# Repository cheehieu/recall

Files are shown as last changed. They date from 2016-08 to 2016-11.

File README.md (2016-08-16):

# Overview
Originally called "Reminder", this project is the brainchild of Joel Busa. It was intended to help people who have difficulty remembering whether or not they had completed a short, menial task. Users would simply press a button on the Recall device, and an LED would begin to blink for a duration of 30 minutes. If the user pressed the button again before the 30 minutes had elapsed, the LED would turn off.

[state diagram]

The goals of this design were:
* Small
* Low Power
* Stupid Cheap

[concept drawing]

# Hardware
* BOM
* schematics
* layouts
* gerbers, OSH Park links
* cost of build

## Discrete
* Discrete LED flasher circuit with passive components
** LM3909 equivalent
* Coin cell battery, CR2032 is most cost effective for the capacity, CR2450 (600 mAh), CR2477 (1000 mAh)
* Diffuse push button mechanical switch
* Current shunt for power measurement

## Microcontroller
* PIC10(L)F320 for power/cost/size
** ATTINY5 was lowest cost on DigiKey at $0.30 @ 5k, but 200/25 uA active/standby current at 1.8V
** PIC10LF320/322 is more expensive at $0.38 @ 3k, but 25/0.02 uA active/standby current at 1.8V
* Digital LED flasher circuit, isolation diodes
* Requires an ICSP programmer like PICkit 3 on eBay for $15

## Bluetooth Module
* Rigado BMD-300 for availability/libraries/size/power
* Rigado BMD-350 for size
* Hall effect switch for Baby Guardian
* GPIO breakout for tactile push button switch
* SWD interface for programming

## Custom BLE 
* BLE solution in smallest footprint, low cost
* bypass capacitors, DCDC, LF/HF crystals, PCB PIFA antenna, ceramic chip antenna
* shielding, FCC certification, 
* Hall effect switch for Baby Guardian
* GPIO breakout for tactile push button switch
* SWD interface for programming
* Reference Tindie nRF52 dev board

# Firmware
## PIC
## Nordic
Configured as a beacon, update major on button state change (indicates status in advertising packet to listening phone)
* battery level
* RSSI for distance

# Software
## Android
## iOS
## React Native

# Mechanical
* Silicone button with conductive pad
* Translucent key caps

* 3D design files for enclosure
* 3D design files for Baby Guardian clip
* 3D printed results

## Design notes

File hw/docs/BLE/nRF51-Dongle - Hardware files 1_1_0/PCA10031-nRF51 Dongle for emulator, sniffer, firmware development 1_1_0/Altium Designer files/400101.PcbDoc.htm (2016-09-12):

Reporting Options

# File in Previous Format

Date | : | 9/11/2016
Time | : | 3:55:51 PM
Filename | : | C:\Users\Hieu\Documents\GitHub\recall\hw\docs\BLE\nRF51-Dongle - Hardware files 1_1_0\PCA10031-nRF51 Dongle for emulator, sniffer, firmware development 1_1_0\Altium Designer files\400101.PcbDoc

Version | Warning

This file was generated by an earlier version of the software

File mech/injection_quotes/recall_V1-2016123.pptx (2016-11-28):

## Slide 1

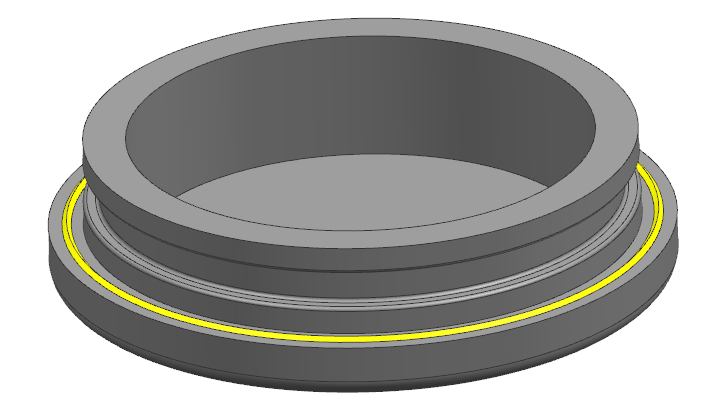
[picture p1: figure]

2. recall_oring_bottom

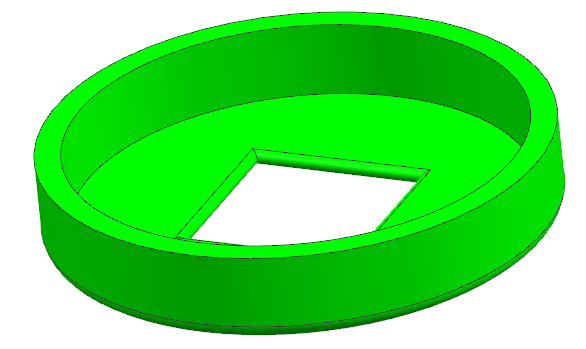
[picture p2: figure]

Suggest using ultrasonic bonding

1.recall_top

Notes:
a. In order to simplify tooling, suggest doing groove on bottom part.
b. Suggest using POM material for these two parts, for its high mechanical strength , and better effect to press the o-ring.

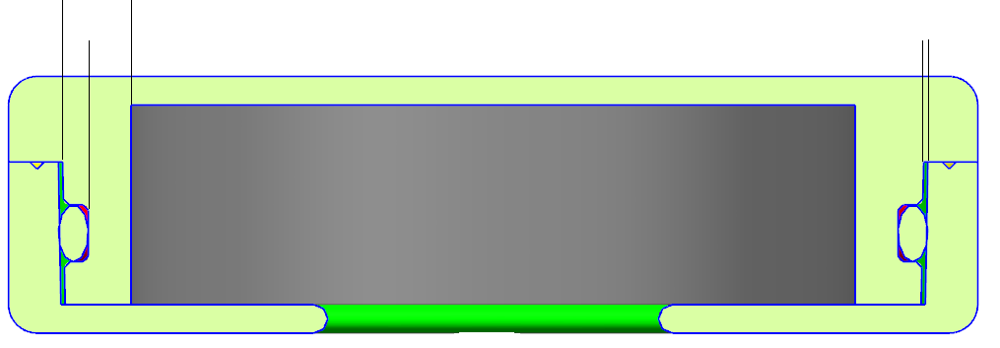
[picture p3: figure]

2.4mm

1.5mm

2. recall_oring_bottom

The gap is 0.15mm

3. o-ring( standard part)

1.recall_top

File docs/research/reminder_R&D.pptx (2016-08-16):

## Reminder R&D

Hieu Nguyen
Intuitive Machines
July 1, 2016

## Reminder

- Overview
  - All hardware
  - Waterproof
  - Stupid cheap
- Usage
  - Press button and an LED blinks lighting up button
  - Blinks for 30 minutes or until pressed again
  - Stick around the house, shower, etc.
- Misc.
  - Battery life should last two years
  - Blink frequency as slow as 1 Hz
  - Target price <$2 at high quantities

Reset

PB

OFF

LED Blink

PB | 30 minutes

## Components

- Transparent silicon rubber button
- 555 timer
- Low power LED
- Watch battery
- Sticky tape for mounting

## Power Analysis

- Requirements:
  - 2 year battery life
  - 30 minute continuous runtime
  - Small “watch battery” button cell
- CR2032 3V 225mAh coin cell ($0.17)
  - 2 years = 17520 hours
  - Max Avg Current = 0.7 * 225 mAh / 17520 hours = ~9 uA

## Solutions

1. Push button control
2. 30 minute timeout
3. Blink LED
- MCU (ATtiny13a)
- 555 CMOS timer
- General purpose 16-stage timer (daisy chained)
- Flip flop
- Multivibrator transistor circuit
- LM3909 LED flasher
- NAND gate multivibrator circuit

## 555 Timer

- Low cost vs. power efficiency
- 30 minute one-shot timer
  - T = 1.1 * R [ohms] * C [Farads] seconds
  - 2 resistors, 2 caps
- LED flasher
  - T = 1 / (0.7*(RA+2RB)*C)
  - F = 1 / (0.693(2R)C Hz [50% duty cycle]
  - 2 resistors, 2 capacitors

## Discrete Multivibrator

- Bistable for storing button input
- Monostable for one shot timer
- Astable for blinking LED
- High freq pulse, divided down with Ripple Counter
- NAND gate waveform generator

## LEDs

- Our eyes perceive different colors at different brightnesses, even though a light might indicate they are the same. Blue and green LEDs always look brighter than red and yellows for the same given mcd output.
- LEDs with lower forward voltage (usually red) can extend battery life (will be operational when battery is at lower voltage)
- Low V_f, high mcd, low current, low cost, 360 degree visibility

## BOM

- Push button, keyboard transparent switch
- Control circuit, Timer
- LED
- Battery
- PCB, PCBA
- Enclosure
- Mount

## Extensions

- Bluetooth connected button
- Oil/water mixture, like lava lamp timer
- Used for old people with poor memories to verify if they completed a task

## Azoteq Reverse Engineer

- JANSPORT

Designator | Part # | Description
CONN | | Battery holder for 2 CR2016 coin cells
BAT | CR2016 | Coin cell batteries x2 for 6V input
BTN | | Tactile button
LED | | White LED
U1 | IQS703 | 6-pin MCU
C1, C2 | | Bypass capacitors
D1 | KL1
R1 | | 82.5 ohms
T1…5 | | Test points

## Azoteq Reverse Engineer

- Hacked Sample

Designator | Part # | Description
CONN | | Battery holder for CR2032 coin cell
BAT | CR2032 | Coin cell battery
BTN | | Tactile button
C_btn
LED | | White LED
U1 | | 8-pin
R3 | | 220 ohms
R3.5 | | 10k ohms
U2 | GG5 | LDO? PIN diodes?
D1 | KL1, BAT54 | Schottky diodes
C1
D2
T1…5 | | Test points

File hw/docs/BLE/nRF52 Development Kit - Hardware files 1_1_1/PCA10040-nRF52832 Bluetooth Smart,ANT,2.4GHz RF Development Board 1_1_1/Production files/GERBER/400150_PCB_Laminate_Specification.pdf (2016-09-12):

### PCB Laminate Specification

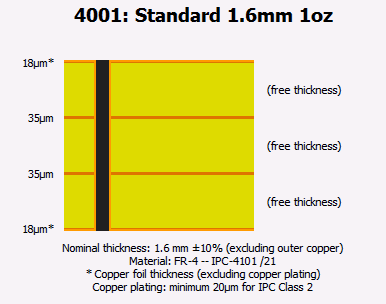
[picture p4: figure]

Page 1 of 1 | Rev. 1.0.0, 2016-03-10

PCB laminate parameters

PCB code | 4000150
Number of copper layers | 4 layers
Laminate material | FR4
Total board thickness | 1.6mm
PCB stackup | See Figure 1
Copper thickness | See Figure 1
Surface finish | Lead-Free HASL
Compliance with environmental directives | RoHS

Table 1: PCB substrate details

The PCB layer stackup order (from top layer and down) shall be as follows with reference to the Gerber file extensions given below:

- Top layer: | .GTL
- Mid layer 1: | .G1
- Mid layer 2: | .G2
- Bottom layer: | .GBL

Stackup

Figure 1: Elprint's standard 4 layer 4001 stackup

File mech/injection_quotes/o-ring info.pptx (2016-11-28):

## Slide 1

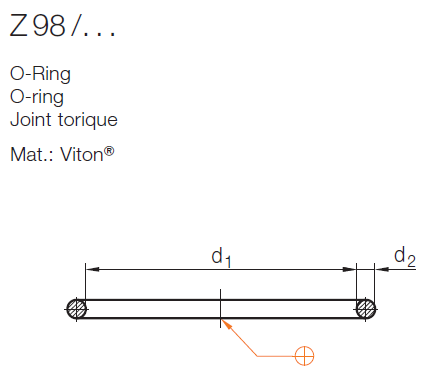
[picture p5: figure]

HASCO: Z98/3.8/1.5

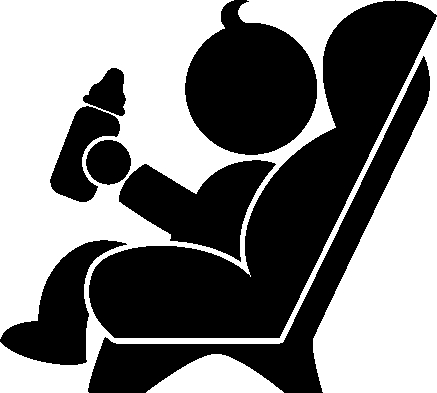
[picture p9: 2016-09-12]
hw/docs/Silk/baby_carseat.jpg

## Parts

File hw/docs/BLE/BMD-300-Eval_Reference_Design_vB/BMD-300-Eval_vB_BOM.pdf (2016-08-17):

Component list | BMD-300-Eval
Source Data From: | BMD-300-Eval.PrjPcb
Project: | BMD-300-Eval
Version: | vB
Report Date: | 2/10/2016 | 2:49:44 PM
Print Date: | 22-Apr-16 | 1:58:11 PM
# | Part Number | Description | Value | Manufacturer | Manufacturer P/N | Supplier 1 | Supplier Part Number 1 | Designator | Quantity

1 | 100-00005 | XTAL, 2Pin, 32.768kHz, 7pF 20ppm | | Abracon LLC | ABS07-32.768KHZ-7-T | Digi-Key | 535-9543-1-ND | X1 | 1
2 3 | 100-00013 | 12MHz ±30ppm Crystal 18pF | | TXC CORPORATION | 7M-12.000MAAJ-T | Digi-Key | 887-1121-1-ND | X2 | 1
| 110-00008 | DIODE SCHOTTKY 20V 500MA SOD123 | | Fairchild Semiconductor | MBR0520L | Digi-Key | MBR0520LCT-ND | D8, D9, D10 | 3
4 5 | 110-00018 | LOW-CAPACITANCE 3-CHANNEL ESD- | | Texas Instruments | TPD3E001DRLR | Digi-Key | 296-21885-1-ND | D7 | 1
| 110-00019 | ESD9B3.3ST5G | | ON Semiconductor | ESD9B3.3ST5G | Digi-Key | ESD9B3.3ST5GOSCT-ND | D1, D2, D3, D4 | 4
6 7 | 115-00019 | LED GREEN CLEAR 0603 SMD | | Lite-On Inc | LTST-C190KGKT | Digi-Key | 160-1435-1-ND | D5, LED3, LED4 | 3
| 115-00020 | LED RED CLEAR 0603 SMD | | Lite-On Inc | LTST-C191KRKT | Digi-Key | 160-1447-1-ND | D6, LED1, LED2 | 3
8 9 | 130-00008 | USB Micro B Receptacle, Right Angle, SMT with 2 TH | | FCI | 10118193-0001LF | Digi-Key | 609-4616-1-ND | J4 | 1
| 130-00099 | CON HDR 0.05" 10Pin 2Row SMD Black | | Samtec | FTSH-105-01-F-DV-K | Digi-Key | SAM8796-ND | J3 | 1
10 11 | 130-00098 | CON FFC/FPC 0.50mm 5Pos R/A | | Molex Inc | 0512810594 | Digi-Key | WM9836CT-ND | J1 | 1
| 130-00101 | Con Socket Strip 0.1" 10Pin 1Row SMD | | Sullins Connector Solutions | NPPC101KFXC-RC | Digi-Key | S5641-ND | J6, J9 | 2
12 13 | 130-00102 | Con Socket Strip 0.1" 8 Pin 1Row SMD | | Sullins Connector Solutions | NPPC081KFXC-RC | Digi-Key | S5639-ND | J5, J7 | 2
| 130-00103 | Con Socket Strip 0.1" 6Pin 1Row SMD | | Sullins Connector Solutions | NPPC061KFXC-RC | Digi-Key | S5637-ND | J8 | 1
14 15 | 130-00104 | Header 0.1" 6 Pin 2 Row SMD Black | | Molex Inc | 0015912060 | Digi-Key | WM17449-ND | J11 | 1
| 130-00105 | Header, 0.100" Pitch, 3 Pin, Vertical SMT | | Harwin Inc | M20-8770342 | Digi-Key | 952-1951-ND | J22, J23 | 2
16 17 | 135-00002 | Tactile Switch, SPST-NO, SMT 160gf. | | C&K Components | PTS645SM43SMTR92 LFS | Digi-Key | CKN9112CT-ND | SW1, SW2, SW3, SW4, SW5 | 5
| 137-00006 | SWITCH SLIDE DPDT 300MA 6V SMD | | C&K Components | JS202011SCQN | Digi-Key | 401-2002-1-ND | SW6 | 1
18 19 | 140-00019 | Mosfet, Dual, N-Channel and P-Channel Pair, 20V | | Diodes Incorporated | DMC2990UDJ-7 | Digi-Key | DMC2990UDJ-7DITR-ND | Q1 | 1
| 180-00020 | Resistor 0 ohm 1/16W 0402 | 0 | Rohm Semiconductor | MCR01MRTJ000 | Digi-Key | RHM0.0CECT-ND | R1, R2 | 2
20 21 | 200-00028 | IC MCU 32BIT 128KB FLASH 100LQFP | | Atmel | ATSAM3U2CA-AU | Digi-Key | ATSAM3U2CA-AU-ND | U2 | 1
| 205-00011 | Bluetooth 4.2 LE SoM, 512kB Flash, 64kB RAM, | | Rigado | BMD-300-A | Digi-Key | 1604-1006-1-ND | U1 | 1
22 23 | 260-00024 | IC REG LDO 3.3V 0.3A SOT23-5 | | Diodes Incorporated | AP2127K-3.3TRG1 | Digi-Key | AP2127K-3.3TRG1DICT-ND | U3 | 1
| 120-00016 | Cap, Ceramic 0.1uF 10V 10% X5R 0402 | 0.1uF | Murata Electronics North America | GRM155R61A104KA01J | Digi-Key | 490-6297-1-ND | C6, C7, C8, C9, C13, C14, C15, C16, C17, C18, C19, C23, C24, C25, C26, C28 | 16
24 25 | 120-00017 | Cap, Ceramic, 1.0uF 10V 10% X5R, 0402 | 1.0uF | Murata Electronics North | GRM155R61A105KE15D | Digi-Key | 490-3890-1-ND | C29, C30 | 2
| 180-00021 | Resistor 1k ohm 1% 1/16W, 0402 | 1k | Rohm Semiconductor | MCR01MRTF1001 | Digi-Key | RHM1.00KCDCT-ND | R14, R17, R22, R24 | 4
26 27 | 180-00121 | RES SMD 4.7K OHM 1% 1/16W 0402 | 4.7k | Samsung Electro-Mechanics | RC1005F472CS | Digi-Key | 1276-3466-1-ND | R9, R10, R11, R16 | 4
| 120-00032 | Cap, Ceramic 4.7uF 16V 10% X5R 0603 | 4.7uF | Samsung Electro-Mechanics | CL10A475KO8NNNC | Digi-Key | 1276-1784-1-ND | C1 | 1
28 29 | 120-00048 | Cap, Ceramic 6pF 50V NP0 0402 Tolerance = +/-0.5pF | 6pF | Murata Electronics North | GRM1555C1H6R0DA01D | Digi-Key | 490-5877-1-ND | C4, C5 | 2
| 180-00068 | Resistor 6.8k ohm 1%, 1/16W, 0402 | 6.8k | Rohm Semiconductor | MCR01MRTF6801 | Digi-Key | RHM6.8KCDCT-ND | R15 | 1
30 31 | 180-00024 | Resistor 10k ohm 1% 1/16W, 0402 | 10k | Rohm Semiconductor | MCR01MRTF1002 | Digi-Key | RHM10.0KCDCT-ND | R12, R13, R18, R26 | 4
| 120-00084 | CAP CER 10000PF 16V X7R 0402 | 10nF | Samsung Electro-Mechanics | CL05B103KO5NNNC | Digi-Key | 1276-1051-1-ND | C22 | 1
32 33 | 120-00065 | Cap, Ceramic, 10pF 50V 5% NPO 0402 | 10pF | Murata Electronics North | GRM1555C1H100JA01D | Digi-Key | 490-5921-1-ND | C10 | 1
| 120-00024 | Cap, Ceramic 10uF 10V 20% X5R 0603 | 10uF | Murata Electronics North | GRM188R61A106ME69D | Digi-Key | 490-10475-1-ND | C20, C21, C27 | 3
34 35 | 120-00041 | Cap, Ceramic 18pF 50V 5% NP0 0402 | 18pF | Murata Electronics North | GRM1555C1H180JA01D | Digi-Key | 490-5858-1-ND | C11, C12 | 2
| 180-00006 | Resistor 27 ohm 5%, 1/10W, 0603 | 27 | Rohm Semiconductor | MCR03ERTJ270 | Digi-Key | RHM27CGCT-ND | R23, R25 | 2
36 37 | 180-00056 | Resistor 220 ohm 1%, 1/16W, 0402 | 220 | Panasonic Electronic | ERJ-2RKF2200X | Digi-Key | P220LCT-ND | R20, R21 | 2
| 180-00098 | RC1005J221CS | 220 | Samsung Electro-Mechanics | RC1005J221CS | Digi-Key | 1276-4360-1-ND | R5, R6, R7 | 3
36 39 | 180-00109 | RES SMD 1 OHM 1% 1/10W 0603 | 1 | Samsung Electro-Mechanics | RC1608F1R0CS | Digi-Key | 1276-4471-1-ND | RSHD,RBMD | 2
| 120-00099 | CAP CER 300PF 50V NP0 0402 | 300pF | Murata Electronics North | GRM1555C1H301JA01D | Digi-Key | 490-3234-1-ND | C2, C3 | 2

### Approved

40 | 180-00031 | Resistor 499 ohm 1%, 1/16W, 0402 | 499 | Rohm Semiconductor | MCR01MRTF4990 | Digi-Key | RHM499CDCT-ND | R3, R4, R8 | 3
41 | Bat Holder
Bat Holder CR2032 SMD | Bat Holder | Harwin Inc | S8211-46R | Digi-Key | 952-1735-1-ND | Bat1 | 1
| | | Notes | | | | 95
Altium Limited Confidential | 4/22/2016 | Page 1

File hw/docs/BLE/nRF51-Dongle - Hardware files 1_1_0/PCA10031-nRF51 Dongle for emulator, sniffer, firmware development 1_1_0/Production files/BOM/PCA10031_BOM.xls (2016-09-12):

Bill of material
PCB: | PCA10031
Version: | 1.1.0
Designator | Value | Description | Footprint Doc | Manufacturer | Manufacturer Part Number
C1, C2, C12, C13 | 12pF | Capacitor, NP0, ±2% | 0402
C3 | 2.2nF | Capacitor, X7R, ±10% | 0402
C4, C14 | 1.0pF | Capacitor, NP0, ±0.1pF | 0402
C5 | 3.9pF | Capacitor, NP0, ±0.1pF | 0402
C6 | 1.5pF | Capacitor, NP0, ±0.1pF | 0402
C7, C8, C11, C18, C21, C24, C26, C29, C30, C31, C32, C33, C34, C35, C36, C37, C38, C39 | 100nF | Capacitor, X7R, ±10% | 0402
C9 | 1.0nF | Capacitor, X7R, ±10% | 0402
C10 | 47nF | Capacitor, X7R, ±10% | 0402
C15, C16 | 1.0µF | Capacitor, X7R, ±10% | 0603
C19 | 10pF | Capacitor, NP0, ±2% | 0402
C20, C25, C27 | 10µF | Capacitor, X5R, ±20% | 0603
C22, C23 | 18pF | Capacitor, NP0, ±5% | 0402
C28 | 10nF | Capacitor, X7R, ±10% | 0402
D1, D3 | 1PS79SB30.115 | Diode Schottky Vf=0.38, Vr=40V, If=200mA, Ir=500nA | SOD-523 | NXP | 1PS79SB30.115
D2 | PRTR5V0U2X | Ultra low capacitance double rail-to-rail ESD protection diode | SOT-143B | NXP | PRTR5V0U2X
L1 | 4.7nH | Inductor, 160mA, ±0.1nH | 0402 | Murata | LQP15MN4N7B02D
L2 | 27nH | Inductor, 70mA, ±2% | 0402 | Murata | LQP15MN27NG02D
L3 | 3.3nH | Inductor, 190mA, ±0.1nH | 0402 | Murata | LQP15MN3N3B02D
L4 | 1.8nH | Inductor, 280mA, ±0.1nH | 0402 | Murata | LQP15MN1N8B02D
LD1 | LED RGB | RGB LED 1.00 mm x 1.00 mm SMD | SML-LX0404SIUPGUSB | Lumex | SML-LX0404SIUPGUSB
LD2 | LTST-C195KGJRKT | Ultra bright AlInGaP Bi-Color LED | LED_DUAL_0606 | Lite-On Inc | LTST-C195KGJRKT
R1 | 10k | Resistor, ±1%, 0.063W | 0402
R3, R4 | 39R | Resistor, ±1%, 0.063W | 0402
R5, R19 | 6k8 | Resistor, ±1%, 0.063W | 0402
R6, R7 | 150R | Resistor, ±1%, 0.063W | 0402
R8, R9, R10, R11 | 4k7 | Resistor, ±1%, 0.063W | 0402
R12 | 2k2 | Resistor, ±1%, 0.063W | 0402
R13 | 680R | Resistor, ±1%, 0.063W | 0402
R14 | 820R | Resistor, ±1%, 0.063W | 0402
R15, R16 | 220R | Resistor, ±1%, 0.063W | 0402
R17 | 0R | Resistor, ±5%, 0.063W | 0402
R18 | 1k | Resistor, ±1%, 0.063W | 0402
R20 | 8k2 | Resistor, ±1%, 0.063W | 0402
SW1 | PTS840 GK SMTR LFS | Microminiature SMT Switch, Side Actuated | PTS840 Gx | C & K | PTS840 GK SMTR LFS
U1 | nRF51422-QFAC | Multi-protocol Bluetooth Low Energy, ANT and 2.4GHz proprietary system-on-chip | QFN-48 | Nordic Semiconductor | nRF51422-QFACAx
U2 | TLV70233DBVT | IC REG LDO 3.3V 300MA SOT23-5 | SOT-23-5 | Texas Instruments | TLV70233DBVT
U3 | ATSAM3U2CA-CU | IC MCU 32bit 128kB flash 100TFBGA | TFBGA100 | Atmel | ATSAM3U2CA-CU
X1 | 16MHz | XTAL SMD 2520, 16MHz, 8pF, ±15ppm | BT-XTAL_2520 | NDK | NX2520SA-16MHZ-STD-CSW-5
X2 | 32.768kHz | EPSON TOYOCOM - FC-135 32.768KHZ ±20PPM,9.0PF - CRYSTAL, SM, WATCH | XTAL_3215 | Epson Toyocom | FC-135 32.768KHZ ±20PPM,9.0PF
X3 | 12MHz | XTAL SMD 3225, 12MHz, 18pF, ±30ppm | BT-XTAL_3225 | TXC Corporation | 7M-12.000MAAJ-T

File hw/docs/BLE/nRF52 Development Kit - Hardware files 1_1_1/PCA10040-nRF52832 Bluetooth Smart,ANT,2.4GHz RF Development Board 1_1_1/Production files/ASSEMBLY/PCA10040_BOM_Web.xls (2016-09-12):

Bill of material
PCB: | PCA10040
Version: | 1.1.1
Designator | Value | Description | Footprint Doc | Manufacturer | Manufacturer Part Number
Bat1 | Bat Holder CR2032 | Bat Holder CR2032 SMD | CR2032_HOLDER_SMD | Comfortable | BC-2001
C1, C2, C11, C12 | 12pF | Capacitor, NP0, ±2% | 0402
C3 | 0.8pF | Capacitor, NP0, ±5% | 0402
C4, C5, C8, C18, C19, C21, C24, C25, C26, C27, C28, C29, C32, C34, C35, C36, C38, C39, C40, C41, C44, C45, C46, C47 | 100nF | Capacitor, X7R, ±10% | 0402
C6, C13 | N.C. | Not mounted | 0402
C7 | 100pF | Capacitor, NP0, ±5% | 0402
C9 | 4.7µF | Capacitor, X5R, ±10% | 0603
C10, C16, C17 | 1.0µF | Capacitor, X7R, ±10% | 0603
C15 | 1.2pF | Capacitor, NP0, ±0.1pF | 0402
C20, C31, C33 | 10µF | Capacitor, X5R, ±20% | 0603
C22, C23 | 18pF | Capacitor, NP0, ±5% | 0402
C30 | 10nF | Capacitor, X7R, ±10% | 0402
C37 | 10pF | Capacitor, NP0, ±2% | 0402
C42, C43 | 300pF | Capacitor, NP0, ±5% | 0402
C48, C49, C50, C51 | 1.0µF | Capacitor, X5R, ±5% | 0402
D1 | SD103ATW-7-F | Surface Mount Schottky Barrier Diode Array | SOT-363 | Diodes Incorporated | SD103ATW-7-F
D2 | PRTR5V0U2X | Ultra low capacitance double rail-to-rail ESD protection diode | SOT-143B | NXP | PRTR5V0U2X
D3, D4, D5, D6 | 1PS79SB30.115 | Diode Schottky Vf=0.38, Vr=40V, If=200mA, Ir=500nA | SOD-523 | NXP | 1PS79SB30.115
J1 | MM8130-2600 | Coaxial Connector with Switch | COAXIAL-SWF | Murata | MM8130-2600
J2 | MicroUSB-B | MicroUSB-B-SMT | USB-Micro-B-RA-SMD-PiP | Allen Creations Corp. | AJU55-BS2111-L
L1 | 3.9nH | Inductor, 170mA, ±0.1nH | 0402 | Murata | LQP15MN3N9B02D
L2 | 10µH | Inductor, 80mA, ±10% | 0603 | Taiyo Yuden | LBMF1608T100K
L3 | 15nH | Inductor, 320mA, ±5% | 0402 | Taiyo Yuden | HK100515NJ-T
LD5 | LTST-C195KGJRKT | Ultra bright AlInGaP Bi-Color LED | LED_DUAL_0606 | Lite-On Inc | LTST-C195KGJRKT
LED1, LED2, LED3, LED4 | L0603G | LED SmartLED Green 570nm 0603 | 0603 | OSRAM Opto Semi | LG L29K-G2J1-24-Z
P1, P3 | Socket 1x8 | Socket 1x8, 2.54mm (100mil), SMD | SOCKET_1x8_SMD | WCON | 2171-108MS0CUNR1
P2 | Socket 1x6 | Socket 1x6, 2.54mm (100mil), SMD | SOCKET_1x6_SMD | WCON | 2171-106MS0CUNR1
P4 | Socket 1x10 | Socket 1x10, 2.54mm (100mil), SMD | SOCKET_1x10_SMD | WCON | 2171-110MS0CUNR1
P5 | Pin Hdr 2x3 | Pin Header 2x3, 2.54mm (100mil) SMD | HDR_2x3-SMD | WCON | 1125-1203S0M116R1
P6 | Socket 1x9 | Socket 1x9, 2.54mm (100mil), SMD | SOCKET_1x9_SMD | WCON | 2171-109MS0CUNR1
P7, P9 | Pin List 1x8 | Pin List 1x8, 2.54mm (100mil), SMD | LIST_1x8_SMD
P8 | Pin List 1x6 | Pin List 1x6, 2.54mm (100mil), SMD | LIST_1x6_SMD
P10 | Pin List 1x10 | Pin List 1x10, 2.54mm (100mil), SMD | LIST_1x10_SMD
P11 | Socket 2x3 | Socket 2x3, 2.54mm (100mil), SMD | SOCKET_2x3_SMD-2.54mm-bottom
P12 | Pin List 1x9 | Pin List 1x9, 2.54mm (100mil), SMD | LIST_1x9_SMD
P13, P15 | Pin Header 2x8 | Pin Header 2x8, 2.54mm (100mil) | HDR_2x8
P14 | Pin Header 2x6 | Pin Header 2x6, 2.54mm (100mil) | HDR_2x6
P16 | Pin Header 2x10 | Pin Header 2x10, 2.54mm (100mil) | HDR_2x10
P17 | Pin Header 2x9 | Pin Header 2x9, 2.54mm (100mil) | HDR_2x9
P18, P19 | Pin Header 2x5, 1.27mm | Pin Header 2x5, 1.27mm (50mil), SMD, Keying Shroud | HDR_2x5-SMD-1.27mm | WCON | 3132-10MS0BK00R1
P20 | Pin List 1x8 | Pin List 1x8, 2.54mm (100mil), SMD | LIST_1x8_SMD | WCON | 1125-1108S0M116R2
P21, P22 | Pin List 1x2, Angled | Pin List 1x2, 2.54mm (100mil), Right Angled, SMD | LIST_ANG_1x2-SMD-2.54MM | WCON | 1125B-1102S0Z135R2
P23 | FPC 0.5mm RA SMD | 0.5mm FPC, 5P,Right Angle SMT,Double Contact,H=1.2mm,White, Goldflash | FPC_05P-0.5mm-RA-SMD | WCON | 5141-05RZDNWR02
Q1, Q2 | FDG6321C | Fairchild, FDG6321C, Dual N & P Channel Digital FET | SC70-6 | Fairchild | FDG6321C
R1, R2, R3, R4, R19, R20 | 220R | Resistor, ±1%, 0.063W | 0402
R5, R8, R9, R10, R11, R12 | 10k | Resistor, ±1%, 0.063W | 0402
R6, R27, R28, R37 | N.C. | Not mounted | 0402
R7 | 47k | Resistor, ±1%, 0.063W | 0402
R13, R14 | 39R | Resistor, ±1%, 0.063W | 0402
R15, R16 | 150R | Resistor, ±1%, 0.063W | 0402
R17 | 6k8 | Resistor, ±1%, 0.063W | 0402
R18 | 1k | Resistor, ±1%, 0.063W | 0402
R21, R22, R23, R24, R29, R30 | 4k7 | Resistor, ±1%, 0.063W | 0402
R25, R26, R38 | 0R | Resistor, ±5%, 0.063W | 0402
R31, R32 | 12k | Resistor, ±1%, 0.063W | 0402
R33, R34, R35, R36 | 100k | Resistor, ±1%, 0.063W | 0402
R39 | 1M0 | Resistor, ±1%, 0.063W | 0402
R40, R41, R42, R43 | 18k | Resistor, ±1%, 0.063W | 0402
SW1, SW2, SW3, SW4, SW5 | PB SW | Tactile Switch, SPNO, SMD, 6.5x6.2x2.5mm | ALPS_SKHUxxx010_WO_GND | Dalywell | TS604VM1-025BR-R
SW6 | Switch | SMD slide Switch (ON-ON) | JS202011SCQN | Dalywell | SS206VM-G2-LLR-R
U1 | nRF52832-QFAA | Multi-protocol Bluetooth Low Energy and 2.4GHz proprietary system-on-chip | QFN-48 | Nordic Semiconductor | nRF52832-QFAA
U2 | ATSAM3U2CA-AU | IC MCU 32bit 128kB flash 100LQFP | LQFP-100 | Atmel | ATSAM3U2CA-AU
U3 | AP7333-33SAG-7 | 300mA, Low Quiescent Current, Fast Transient Low Dropout Linear Regulator | SOT-23-3 | Diodes Incorporated | AP7333-33SAG-7
U4, U5, U6 | NX3DV2567 | Low-ohmic four-pole double-throw analog switch | XQFN-16 | NXP Semiconductors | NX3DV2567GU
U7 | PCAL6408A | 8-bit I2C-bus I/O expander with interrupt output | XQFN-16 | NXP Semiconductors | PCAL6408AHK
X1 | 32MHz | XTAL SMD 2016, 32MHz, Cl=8pF, Tol: ±10ppm, Stab: ±10ppm | XTAL_2016 | Epson Toyocom | Q22FA12800025
X2 | 32.768kHz | EPSON TOYOCOM - FC-135 32.768KHZ ±20PPM,9.0PF - CRYSTAL, SM, WATCH | XTAL_3215 | Epson Toyocom | FC-135 32.768KHZ ±20PPM,9.0PF
X3 | 12MHz | XTAL SMD 3225, 12MHz, 18pF, ±30ppm | BT-XTAL_3225 | TXC Corporation | 7M-12.000MAAJ-T

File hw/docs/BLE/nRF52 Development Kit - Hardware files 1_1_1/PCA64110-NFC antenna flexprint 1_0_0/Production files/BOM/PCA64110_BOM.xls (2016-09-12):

Bill of material
PCB: | PCA64110
Version: | 1.0.0
Supplier | Supplier Part Number | Contact information
Elprint Norge | 203406 | Web: www.elprint.no Phone: +47 55 92 55 00

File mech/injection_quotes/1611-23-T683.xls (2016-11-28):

 |  |  |  |  |  |  | China's Leading provider of rapid tooling - at HLH we make things for you. With questions please email your projects contact or info@hlhprototypes.com
Rapid/Prototype Tooling Quotation
Quotation No: |  | 1611-23-T683 |  |  | Date: | 2016-11-23
To: |  | ELLIE GRID |  |  | Attn: | Hieu Nguyen
From: |  | HLH Mold Technology Co Ltd
No. | Image and Part Name | Part Size (mm) | Part Material | Mold Material | Cavities | Mold Cost (USD) | Part Cost (USD/SET) | Qty (PCS) | Total Cost (USD) | Notes
1 | Adafruit Trellis 3mm | 60*60*13.5 | silicone | P20 | 1 | 4600 | 1.52 | 5000 | 12200 | Mold manufacture time: 3 Weeks. Mold polishing grade：SPI-B1. Mold life：100K Shots. Hot embossing. Rapid mold, chinese standard, provid parts only.
2 | Trellis_1x1 | 15*15*11.6 | silicone | P20 | 8 | 3050 | 0.15 | 5000 | 3800 | Mold manufacture time: 3 Weeks. Mold polishing grade：SPI-B1. Mold life：100K Shots. Hot embossing. Rapid mold, chinese standard, provid parts only.
3 | recall_bottom | ø34*8 | PP | P20 | 1+1+1+1 | 3800 | 0.35 | 5000 | 5550 | Mold manufacture time: 3 Weeks. 2 plate mold, cold runner. Side gate. Mold polishing grade：SPI-B1. Mold life：100K Shots. Forced demolding. Rapid mold, chinese standard, provid parts only.
 | recall_oring_bottom | ø34*8 | PP |  |  |  |  | 5000
 | recall_oring_top | ø34*6 | PP |  |  |  |  | 5000
 | recall_top | ø34*6 | PP |  |  |  |  | 5000
Total(USD): |  |  |  |  |  |  |  |  | 21550
Shipping(USD): |  |  |  |  |  |  |  |  | TBD
Total(USD): |  |  |  |  |  |  |  |  | TBD
Remarks： 1. Production lead time starts from the next day after receipt of signed invoice/PO and deposit. 2. Payment terms: 50% deposit with order, 50% upon confirmation of test shots. Unless otherwise agreed. 3. The case under dispute shall be submitted to the arbitration according to Shenzhen Court of International Arbitration. 4. This quotation is valid for 14 days from the date listed above. 5. This quotation does not include tax or shipping unless other wise stated. 6. The above price don't include the packing fee and assembly fee unless otherwise stated. 7. Rapid/Prototype tooling projects often include the use of standard mold bases and as such unless otherwise stated the mold bases remain the property of HLH 8. HLH cannot be held responsible for any loss or damages as a result of parts they have manufactured. 9. Any and all liabilities HLH can be held responsible for shall not exceed the amount received by HLH for the job. 10. Any problems or issues should be report to HLH within 7 days of receipt of parts, any issues discovered after this time are no longer covered by HLH. 11. For rapid tools standard mold bases are used to keep costs down, if the mold is to be taken away from HLH to be used eleswhere the quote may not include the cost of the mold base and an additional fee would be required. 12. For all else please refer to Terms and Conditions.
HLH Mold Technology Co Ltd Office: 1801 Xing Ji Building, Xin Sha Road, Shajing, Shenzhen Factory: Building A, Hongfa Industiral Disctrict, Houda Road, Daling Shan, Dongguan, GuangDong, China Tel: +86-755-82569129 Fax: +86-755-82569136 www.hlhprototypes.com info@hlhprototypes.com

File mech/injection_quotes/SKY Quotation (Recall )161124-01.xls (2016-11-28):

Sky Prototyping and Tooling Co., Ltd.
 |  |  |  |  |  | No.: SKY161124-01
Buyer: | EllieGrid |  |  |  | Vender: | Sky Prototyping and Tooling Co., Ltd.
Contact: | Hieu Nguyen |  |  |  | Contact: | Daisy Yan
TEL: |  |  |  |  | TEL: | 0086 - 18670869863
FAX: |  |  |  |  | FAX: | 0086 - 755 29230538
E-mail: | hieu@elliegrid.com |  |  |  | E-mail: | daisy@sky-pt.com
Website: |  |  |  |  | Website: | www.sky-prototyping-tooling.com
Address: |  |  |  |  | Address: | East Door, 1F, 3rd Bldg., Jinyuda Industrial Park, Shangliao Business Rd., Shajing Street, Baoan District, Shenzhen City, China 518125
No. | 3D | Item Name | Dimensions (mm) | Processing Method | Material | Finish | Mold Material | Cavity | Mold Cost (USD) | Item Unite price (USD) | T1 | Item Quantity (pcs) | Item Total Cost (USD) | Amount (USD) | Note
1 |  | recall_bottom.step | 34*34*8 | Injeciting | ABS | Smooth | 718H | 4*1 | 4048 | 0.1270 | 30 | 5000 | 635 | 6409
2 |  | recall_oring_bottom.step | 34*34*8 |  |  | Smooth |  |  |  | 0.1270 |  | 5000 | 635
3 |  | recall_oring_top.step | 34*34*6 |  |  | Smooth |  |  |  | 0.1191 |  | 5000 | 595.5
4 |  | recall_top.step | 34*34*6 |  |  | Smooth |  |  |  | 0.1191 |  | 5000 | 595.5
5 |  | Adafruit Trellis 3mm.stp | 60*14*60 | Moulding-die | Silicone | Smooth | 718H | 2*1 | 1667 | 0.2620 | 30 | 5000 | 1310 | 3652
6 |  | Trellis_1x1.step | 15*12*15 |  |  | Smooth |  |  |  | 0.1350 |  | 5000 | 675
Amount (USD) |  |  |  |  |  |  |  |  |  |  |  |  |  | $10061
Lead time (working day) |  |  |  |  |  |  |  |  |  |  |  |  |  | 30+12
Terms of payment: TT
 | Beneficiary Bank: HSBC Hong Kong(SWIFT BIC:HSBC HK HHHKH)
 | Beneficiary: HK SKY PROTOTYPING AND TOOLING CO., LIMITED
 | Beneficiary's Account No.: 801-469800-838
 | Beneficiary address: BW001 UNIT 2. 22/F RICHMOND, COMM BLDG 109 ARGYLE ST, MONGKOK KLN, HONG KONG
Terms of payment: Paypal
 | Beneficiary Account: 565369285@qq.com (Please add 4% commission charge to the total cost by paypal payment)
1. This quotation works only after it is signed by the buyer and faxed to the vender
2 Payment terms:50% deposit and 50% balance before shipment.
3. The T1 time will be 30 working days after contract was signed. The products lead time will 12 days after confirmed samples.
4. The charge of tax is excluded in this quotation.
Intellectural property rights and business serect
After the buyer supplies the data to the vender, however whether it is fulfil, the vender has the resposibilities to keep all the technical and design data secret; without the agreement of the buyer, the vender mustn't betray it to the third party(including the vender) for using. If the buyer supplies more strict agreements about the technical and design data,also accepted and signed by two parties, then will be subjected to the secret agreement.
 |  |  |  |  | Daisy Yan
Buyer Signature |  |  |  |  | Vender Signature
2016 |  |  |  |  | 2016

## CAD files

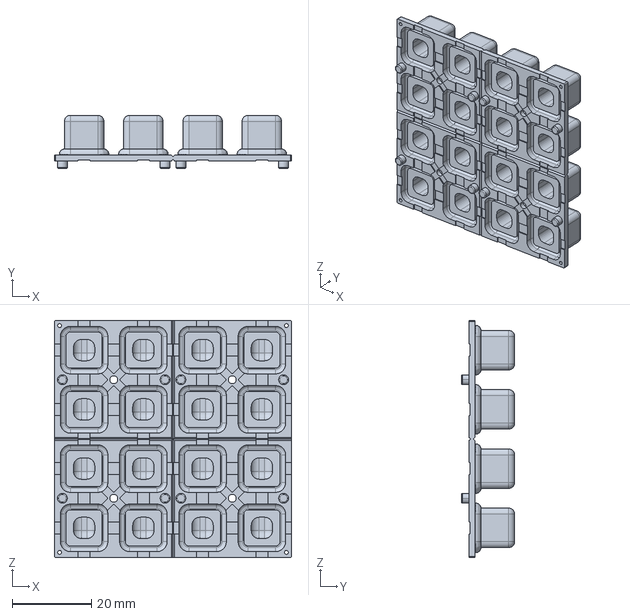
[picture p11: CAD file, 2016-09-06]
hw/docs/Button/Adafruit_Trellis-master/Adafruit Trellis 3mm.stp
60.0 x 13.5 x 60.0 mm

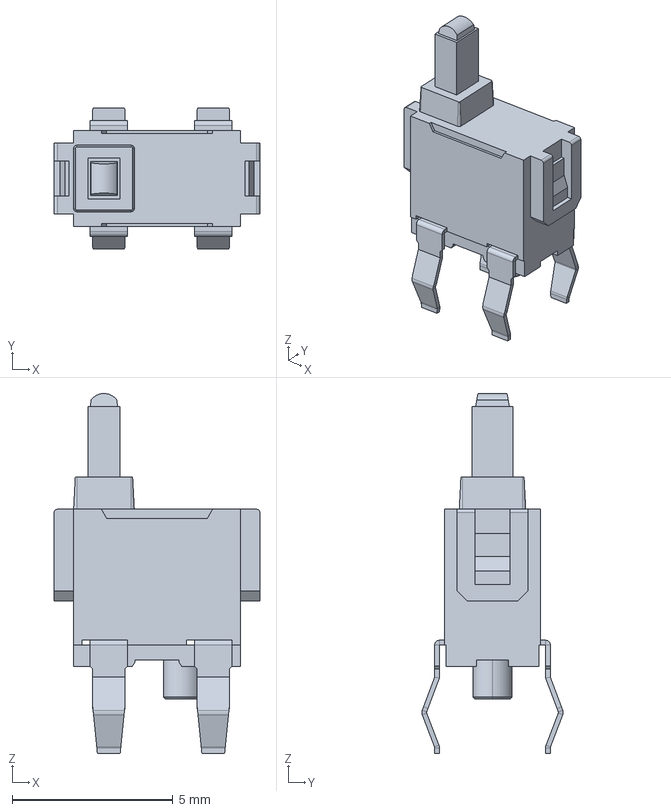
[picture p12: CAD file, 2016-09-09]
hw/docs/Button/dds001.stp
6.40 x 4.40 x 11.2 mm

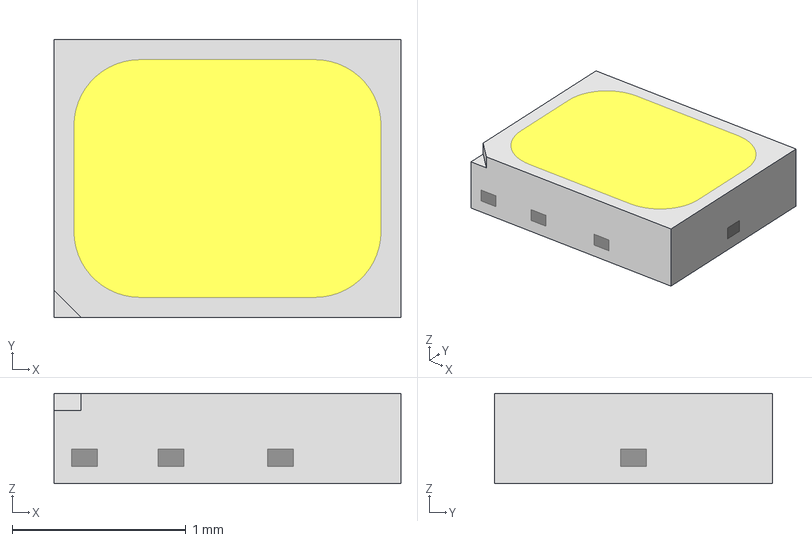
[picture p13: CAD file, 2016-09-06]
hw/docs/LED/MP2016.step
2.00 x 1.60 x 0.52 mm

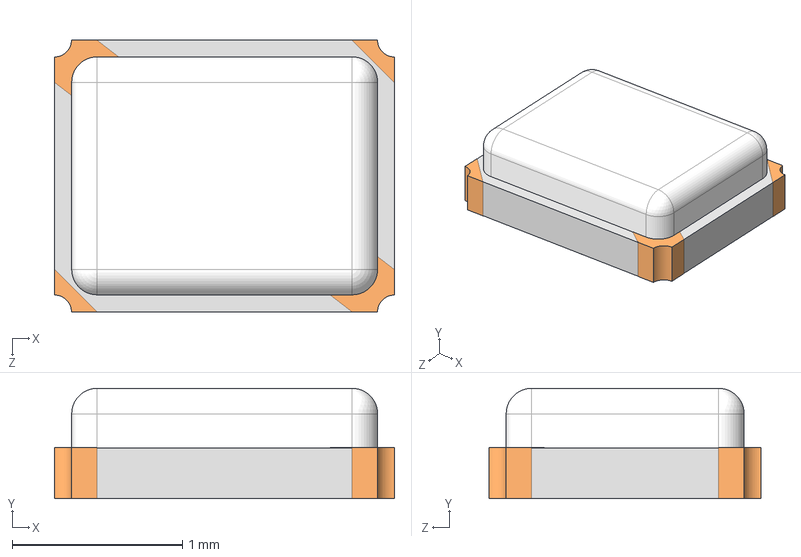
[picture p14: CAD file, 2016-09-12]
hw/docs/Passives/XRCGB27M000F2P00R0.step
2.00 x 0.649 x 1.60 mm

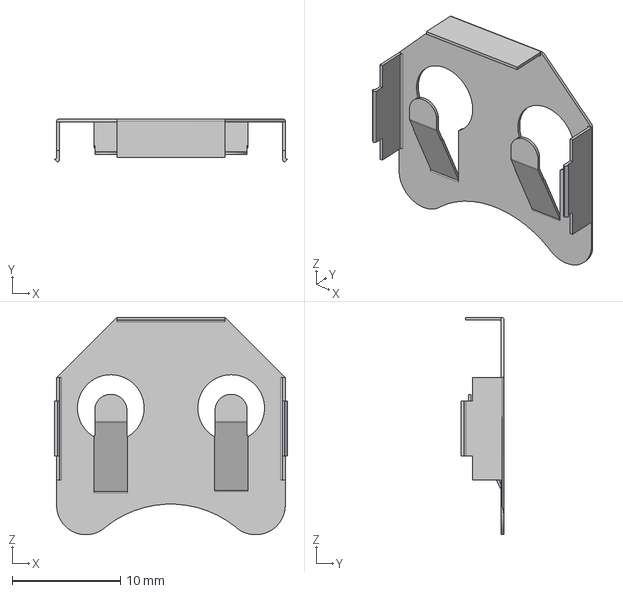
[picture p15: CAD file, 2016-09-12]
hw/docs/Power/bat-hld-001.step
21.5 x 3.96 x 20.1 mm

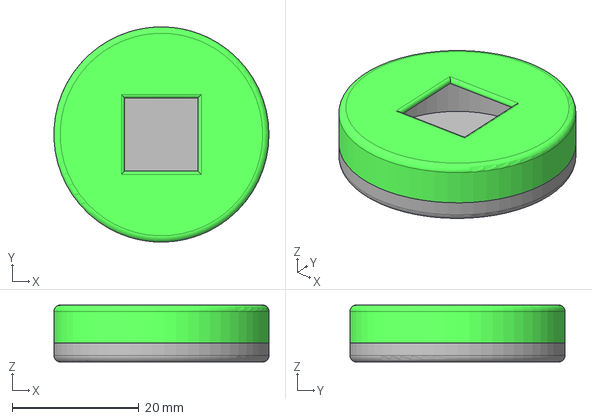
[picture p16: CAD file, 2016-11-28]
mech/injection_quotes/recall_product-20161123.stp
34.0 x 34.0 x 9.00 mm

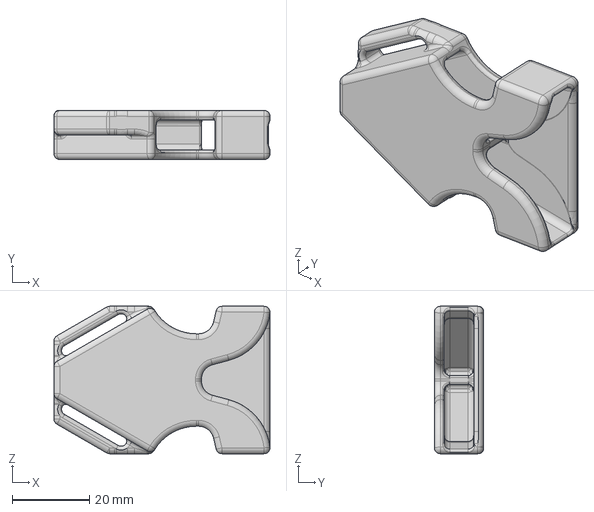
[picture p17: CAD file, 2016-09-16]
mech/recall_clip/recall_clip_female.step
55.8 x 12.7 x 38.1 mm

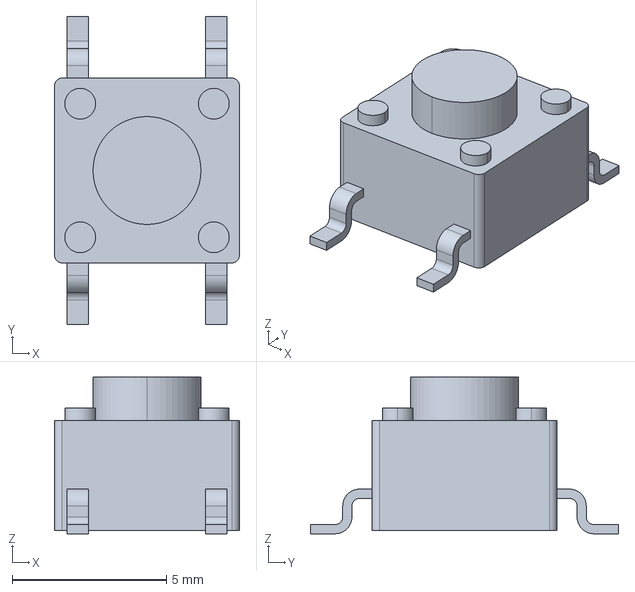
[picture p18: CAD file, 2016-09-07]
hw/docs/Button/4-1437565-1.stp
6.00 x 10.0 x 5.08 mm

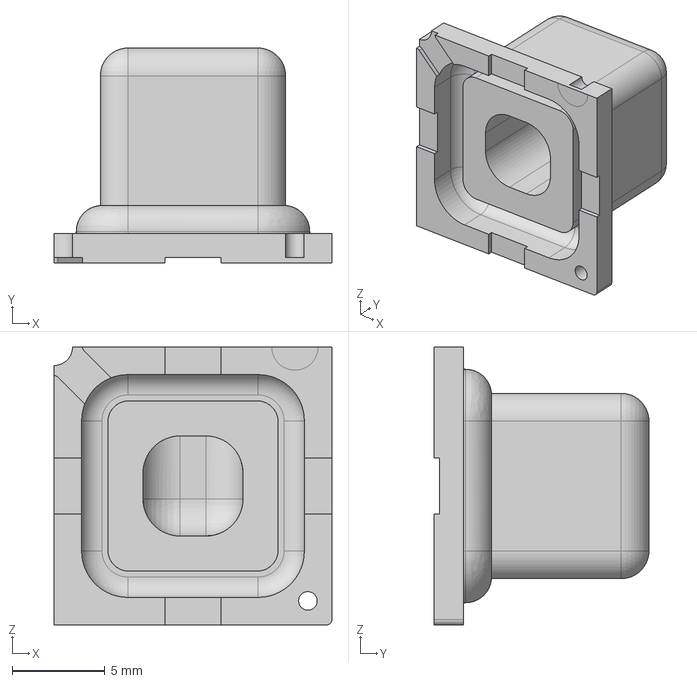
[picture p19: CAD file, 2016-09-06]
hw/docs/Button/Adafruit_Trellis-master/Trellis_1x1.step
15.0 x 11.6 x 15.0 mm

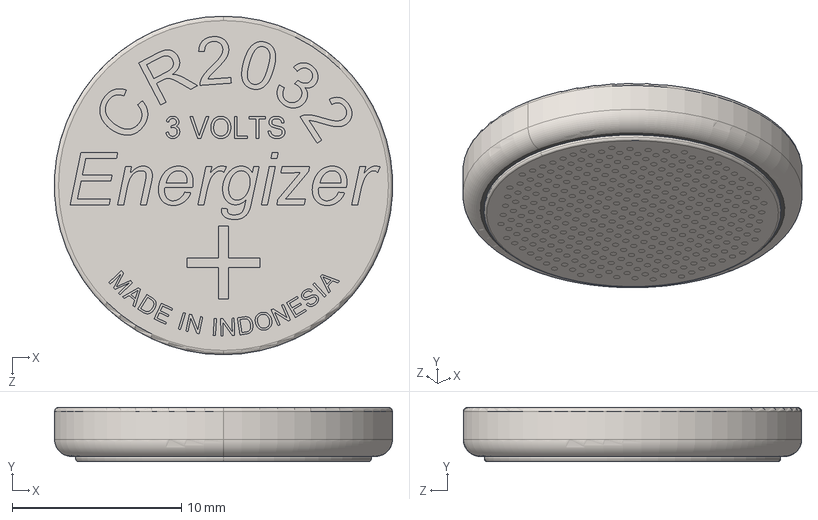
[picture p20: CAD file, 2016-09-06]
hw/docs/Power/2032_battery.STEP
20.0 x 3.20 x 20.0 mm

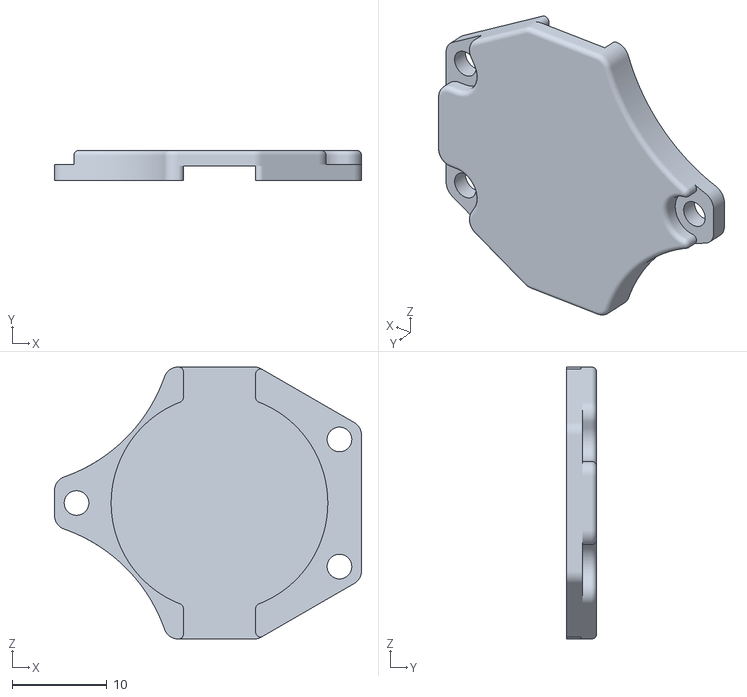
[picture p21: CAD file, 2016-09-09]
mech/bg_clip/cover.stl
32.4 x 3.17 x 28.7

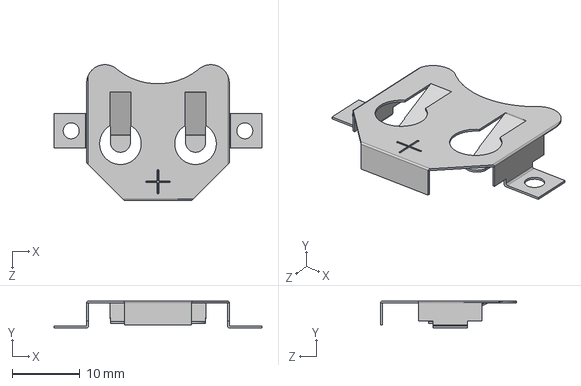
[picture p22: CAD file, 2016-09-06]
hw/docs/Power/keystone_3002_smd_battery_holder.step
30.7 x 3.96 x 20.1 mm

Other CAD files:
fw/PIC10F32x_Source_Code.X/dist/default/production/PIC10F32x_Source_Code.X.production.obj
fw/PIC10F32x_Source_Code.X__/dist/default/production/PIC10F32x_Source_Code.X.production.obj
fw/PIC10F32x_Source_Code.X__/PIC10F32x_Source_Code.X/PIC10F32x_Source_Code.X/dist/default/production/PIC10F32x_Source_Code.X.production.obj
fw/recall_fw_v0_1/dist/default/production/recall_fw_v0_1.production.obj
fw/recall_fw_v0_1/dist/default/production/PIC10F32x_Source_Code.X.production.obj
mech/recall_clip/recall_clip_female_mag.stl
hw/docs/Button/Adafruit_Trellis-master/Adafruit Trellis 3mm.stl
mech/bg_clip/BG_Clip_female.step
mech/bg_clip/BG_Clip_male.step
mech/bg_clip/BG_Clip_male.stl
mech/injection_quotes/Button.x_t
mech/recall_clip/bg_clip_cover.stl
mech/recall_clip/bg_clip_female.step
mech/recall_clip/bg_clip_female.stl
mech/recall_clip/bg_clip_male.step
mech/recall_clip/bg_clip_male.stl
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

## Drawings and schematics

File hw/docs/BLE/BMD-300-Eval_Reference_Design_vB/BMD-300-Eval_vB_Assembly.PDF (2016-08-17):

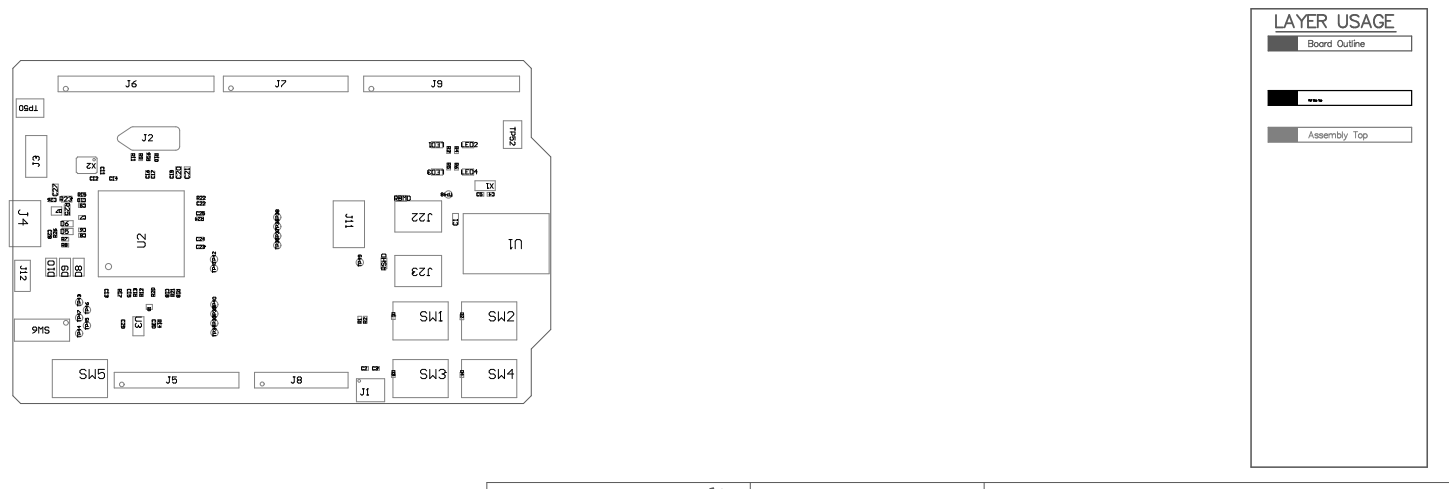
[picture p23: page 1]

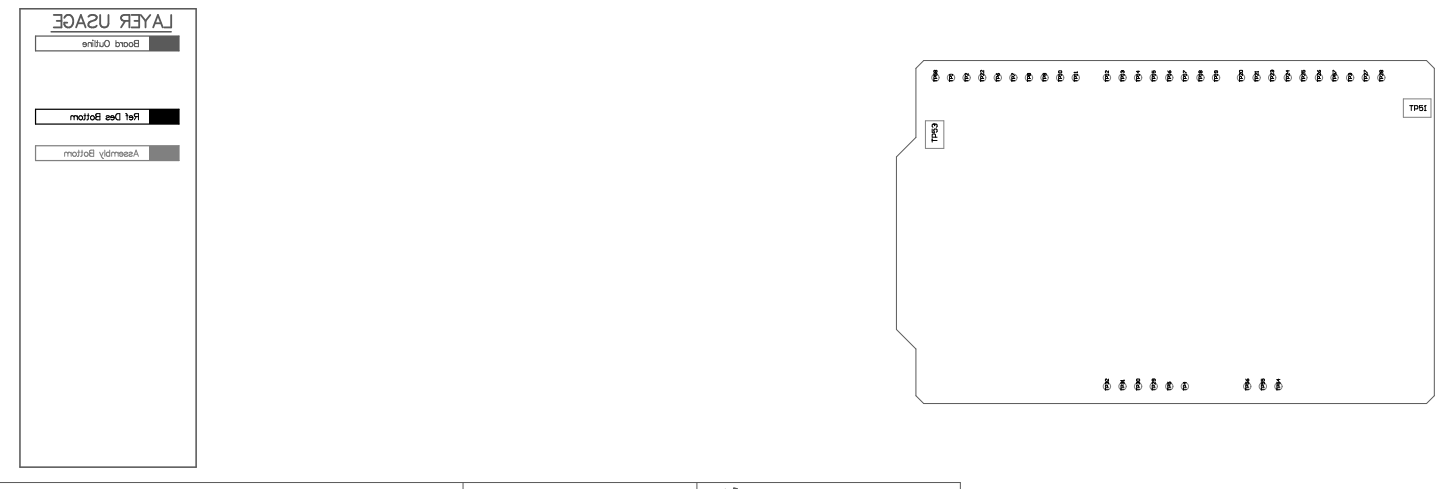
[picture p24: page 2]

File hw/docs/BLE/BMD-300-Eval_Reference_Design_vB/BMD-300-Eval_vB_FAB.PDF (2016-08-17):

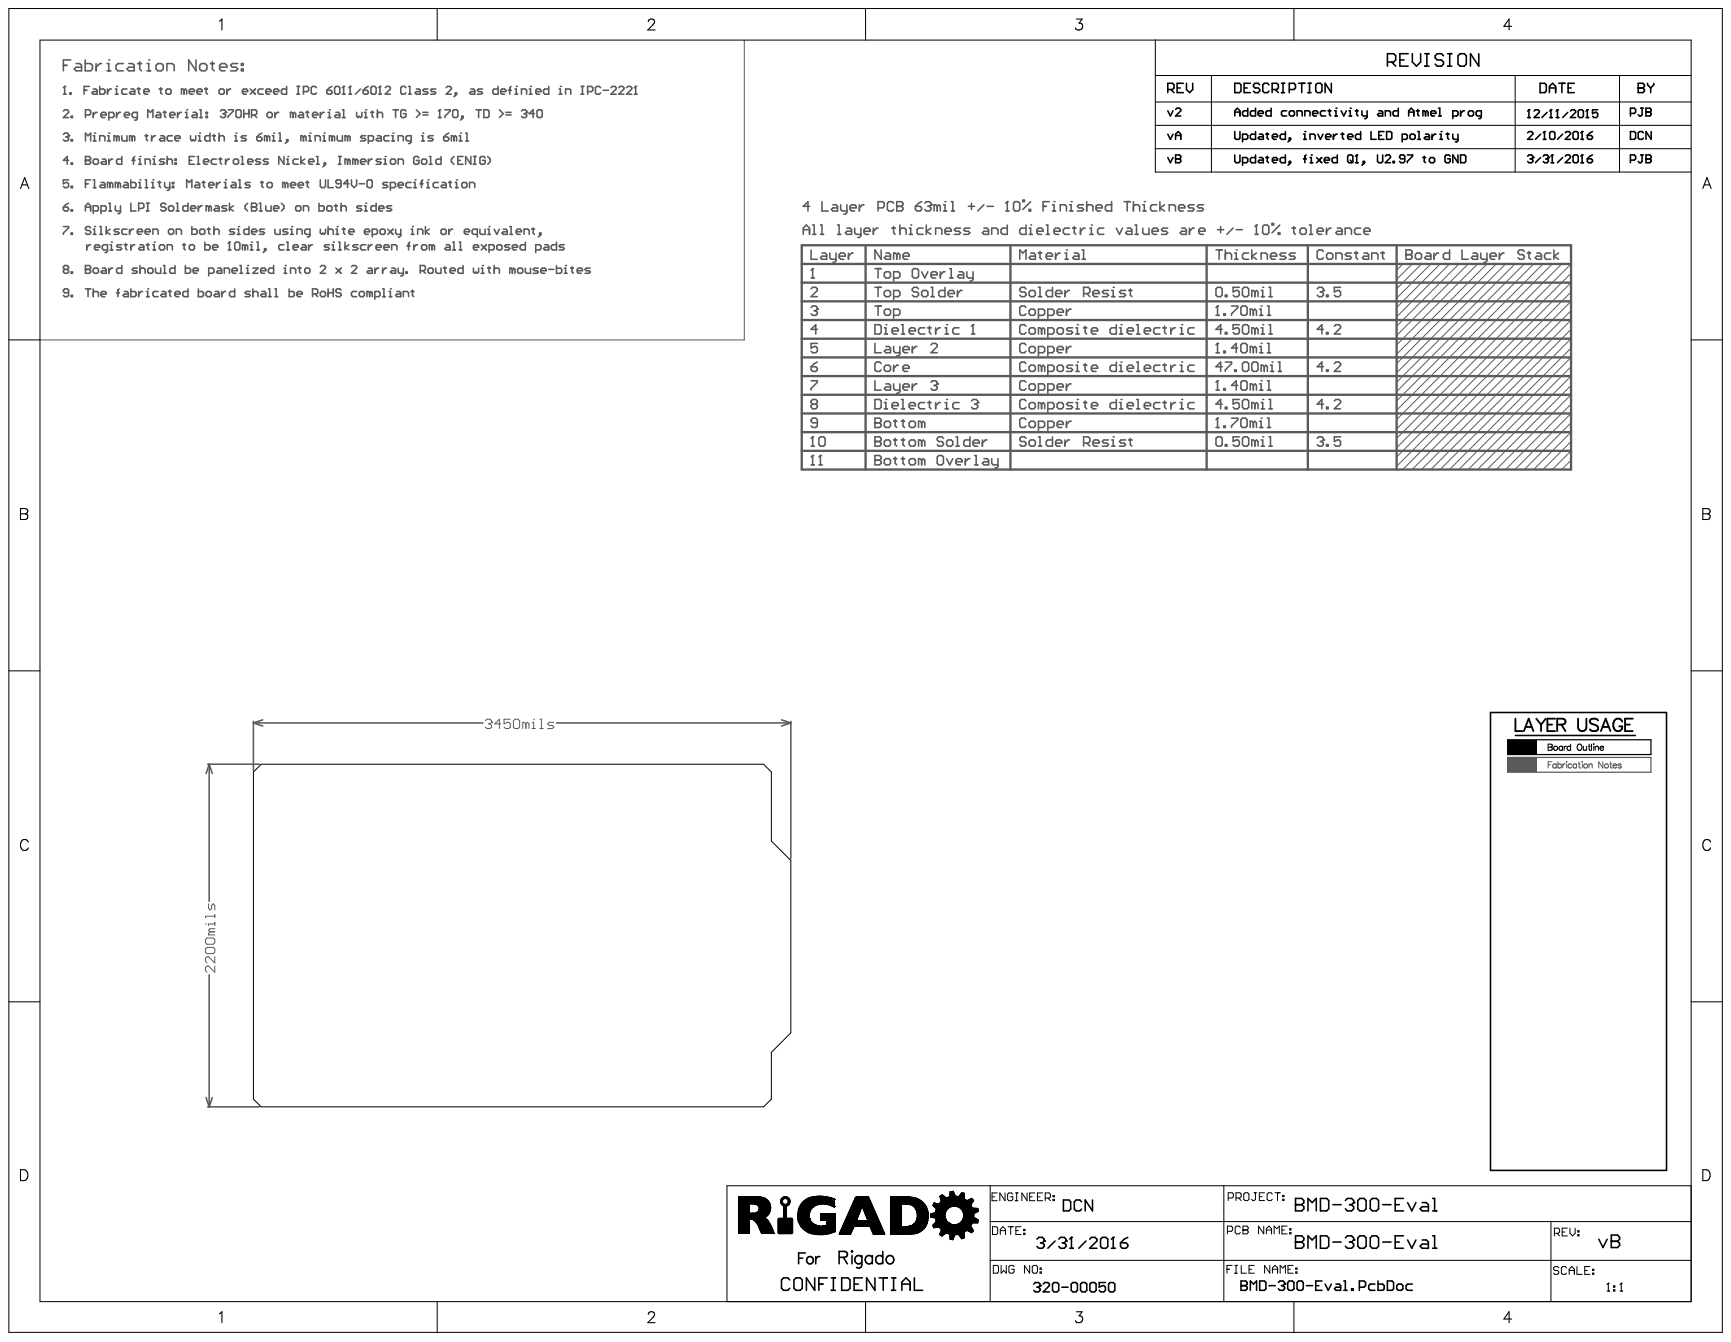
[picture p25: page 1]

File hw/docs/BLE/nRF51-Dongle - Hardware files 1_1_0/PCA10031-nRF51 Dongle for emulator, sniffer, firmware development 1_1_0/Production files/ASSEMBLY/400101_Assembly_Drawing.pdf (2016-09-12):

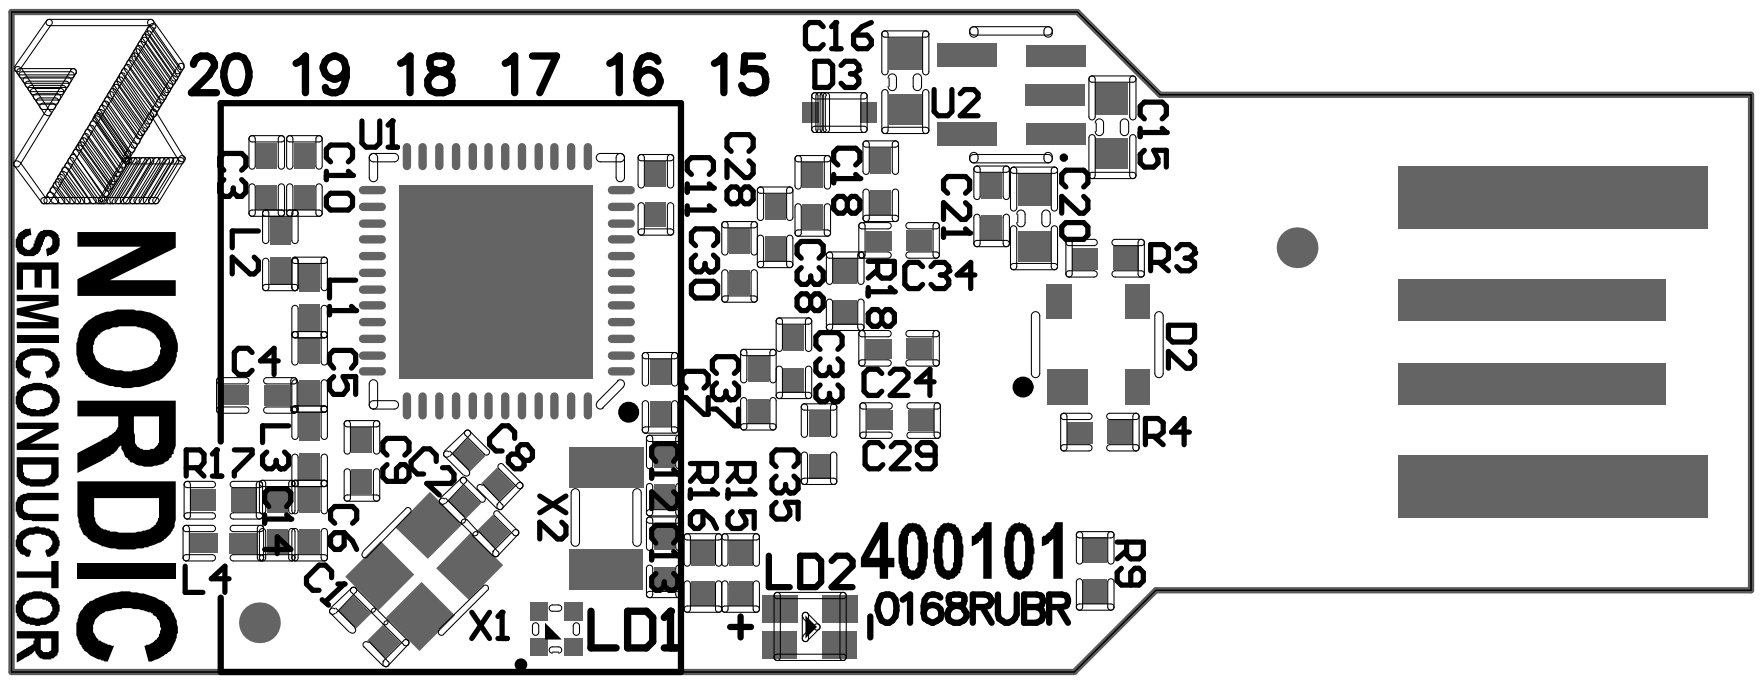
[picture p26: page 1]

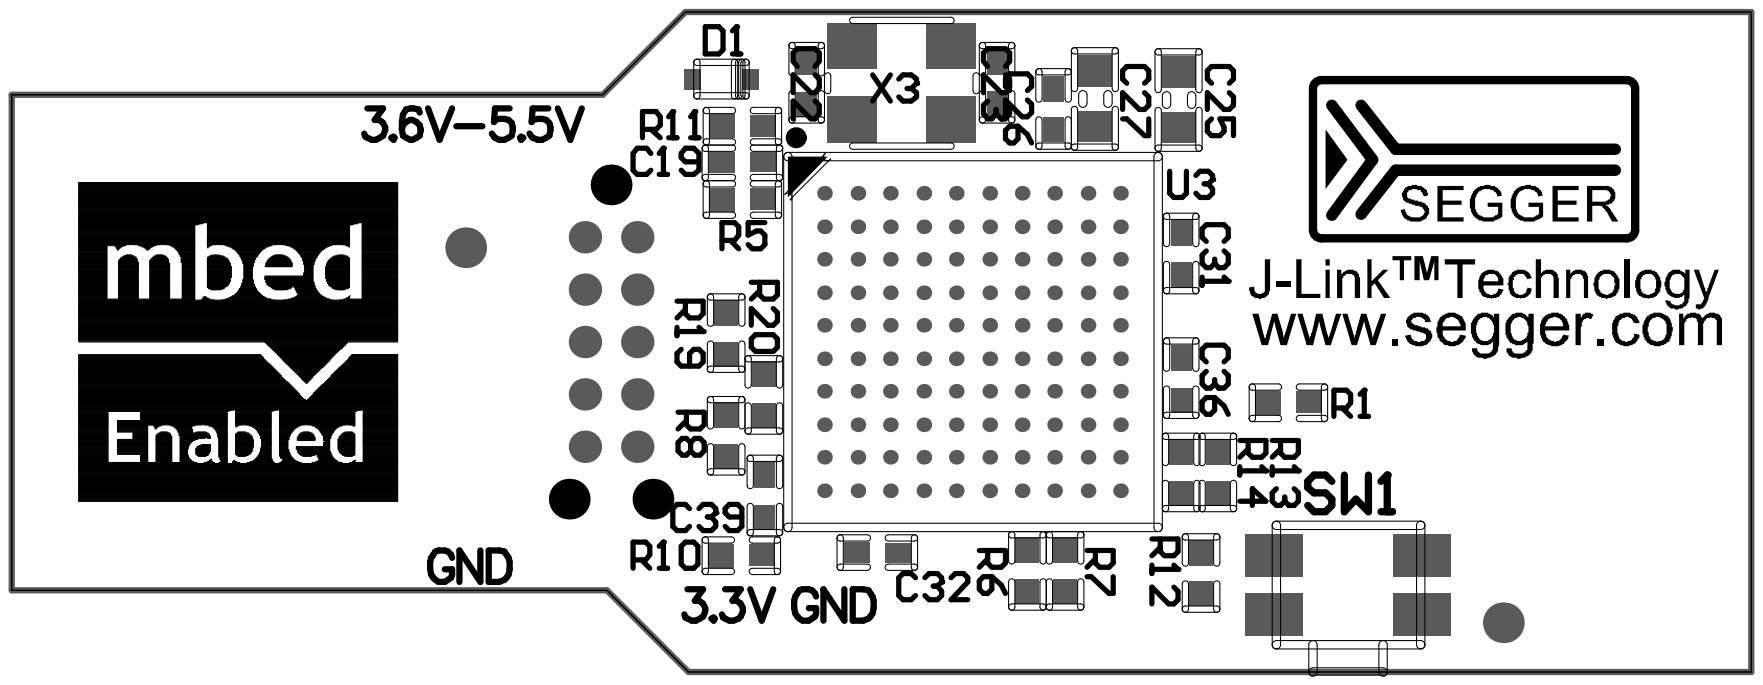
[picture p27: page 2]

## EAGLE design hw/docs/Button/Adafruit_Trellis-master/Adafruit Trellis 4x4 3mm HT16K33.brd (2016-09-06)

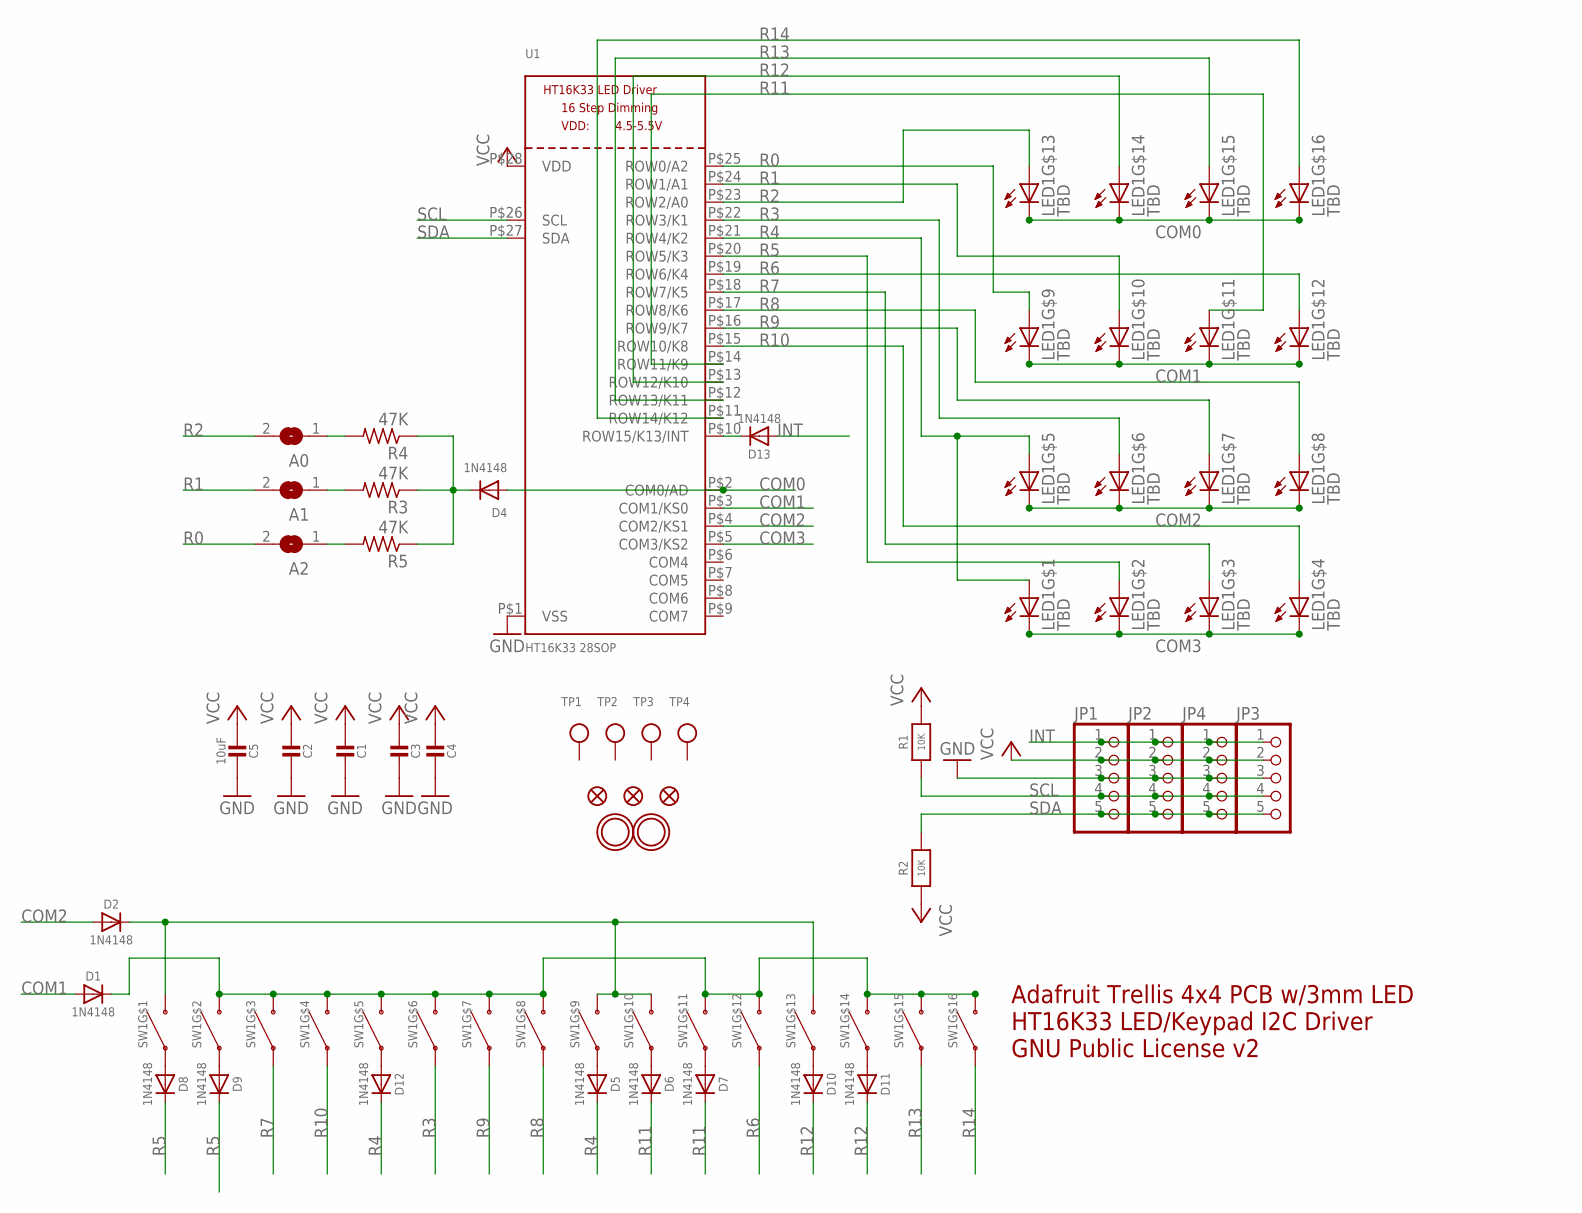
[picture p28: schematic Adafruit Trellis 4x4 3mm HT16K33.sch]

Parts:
A0, A1, A2: SOLDERJUMPERREFLOW_NOPASTE; SOLDERJUMPER_REFLOW_NOPASTE
C1, C2, C3, C4: CAP_CERAMIC_0805; _0805
C5: 10uF; _0805
D1, D2, D5, D6, D7, D8, D9, D10, D11, D12, D13: 1N4148; SOD-323
D4: 1N4148; SOD-323F
FID1, FID2, FID3: FIDUCIAL""; FIDUCIAL_1MM
JP1, JP2, JP3, JP4: HEADER-1X5EDGESMT; 1X5_SMT
LED1: TBD; LED3MM-4X4GRID
R1, R2: 10K; _0805
R3, R4, R5: 47K; R0805
SW1: SWITCH-SILICON-4X4GRID-10MM-5.4MM; ELAST_PAD_SQUARE_10MM_5.4MM_4X4GRID
TP1, TP2, TP3, TP4: TESTPOINT; TESTPOINT_SMT
U1: HT16K33 28SOP; SOP28_300MIL
U$1, U$2: MOUNTINGHOLE2.5; MOUNTINGHOLE_2.5_PLATED

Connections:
COM0: D4.A, LED1.K13 (C), LED1.K14 (C), LED1.K15 (C), LED1.K16 (C), U1.P$2 (COM0/AD)
COM1: D1.A, LED1.K9 (C), LED1.K10 (C), LED1.K11 (C), LED1.K12 (C), U1.P$3 (COM1/KS0)
COM2: D2.A, LED1.K5 (C), LED1.K6 (C), LED1.K7 (C), LED1.K8 (C), U1.P$4 (COM2/KS1)
COM3: LED1.K1 (C), LED1.K2 (C), LED1.K3 (C), LED1.K4 (C), U1.P$5 (COM3/KS2)
GND: C1.1, C2.1, C3.1, C4.1, C5.1, JP1.3, JP2.3, JP3.3, JP4.3, U1.P$1 (VSS)
INT: D13.A, JP1.1, JP2.1, JP3.1, JP4.1
unnamed: D2.C, SW1.B1, SW1.B9, SW1.B10, SW1.B13
unnamed: D13.C, U1.P$10 (ROW15/K13/INT)
unnamed: D5.A, SW1.A9
unnamed: D6.A, SW1.A10
unnamed: D1.C, SW1.B2, SW1.B3, SW1.B4, SW1.B5, SW1.B6, SW1.B7, SW1.B8, SW1.B11, SW1.B12, SW1.B14, SW1.B15, SW1.B16
unnamed: D7.A, SW1.A11
unnamed: D8.A, SW1.A1
unnamed: D9.A, SW1.A2
unnamed: A2.1, R5.2
unnamed: D10.A, SW1.A13
unnamed: D11.A, SW1.A14
unnamed: D12.A, SW1.A5
unnamed: D4.C, R3.1, R4.1, R5.1
unnamed: A1.1, R3.2
unnamed: A0.1, R4.2
R0: A2.2, LED1.A9 (A), U1.P$25 (ROW0/A2)
R1: A1.2, LED1.A10 (A), U1.P$24 (ROW1/A1)
R2: A0.2, LED1.A13 (A), U1.P$23 (ROW2/A0)
R3: LED1.A6 (A), SW1.A6, U1.P$22 (ROW3/K1)
R4: D5.C, D12.C, LED1.A1 (A), LED1.A5 (A), U1.P$21 (ROW4/K2)
R5: D8.C, D9.C, LED1.A2 (A), U1.P$20 (ROW5/K3)
R6: LED1.A12 (A), SW1.A12, U1.P$19 (ROW6/K4)
R7: LED1.A3 (A), SW1.A3, U1.P$18 (ROW7/K5)
R8: LED1.A8 (A), SW1.A8, U1.P$17 (ROW8/K6)
R9: LED1.A7 (A), SW1.A7, U1.P$16 (ROW9/K7)
R10: LED1.A4 (A), SW1.A4, U1.P$15 (ROW10/K8)
R11: D6.C, D7.C, LED1.A11 (A), U1.P$14 (ROW11/K9)
R12: D10.C, D11.C, LED1.A14 (A), U1.P$13 (ROW12/K10)
R13: LED1.A15 (A), SW1.A15, U1.P$12 (ROW13/K11)
R14: LED1.A16 (A), SW1.A16, U1.P$11 (ROW14/K12)
SCL: JP1.4, JP2.4, JP3.4, JP4.4, R1.1, U1.P$26 (SCL)
SDA: JP1.5, JP2.5, JP3.5, JP4.5, R2.2, U1.P$27 (SDA)
VCC: C1.2, C2.2, C3.2, C4.2, C5.2, JP1.2, JP2.2, JP3.2, JP4.2, R1.2, R2.1, U1.P$28 (VDD)

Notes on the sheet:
Adafruit Trellis 4x4 PCB w/3mm LED HT16K33 LED/Keypad I2C Driver GNU Public License v2

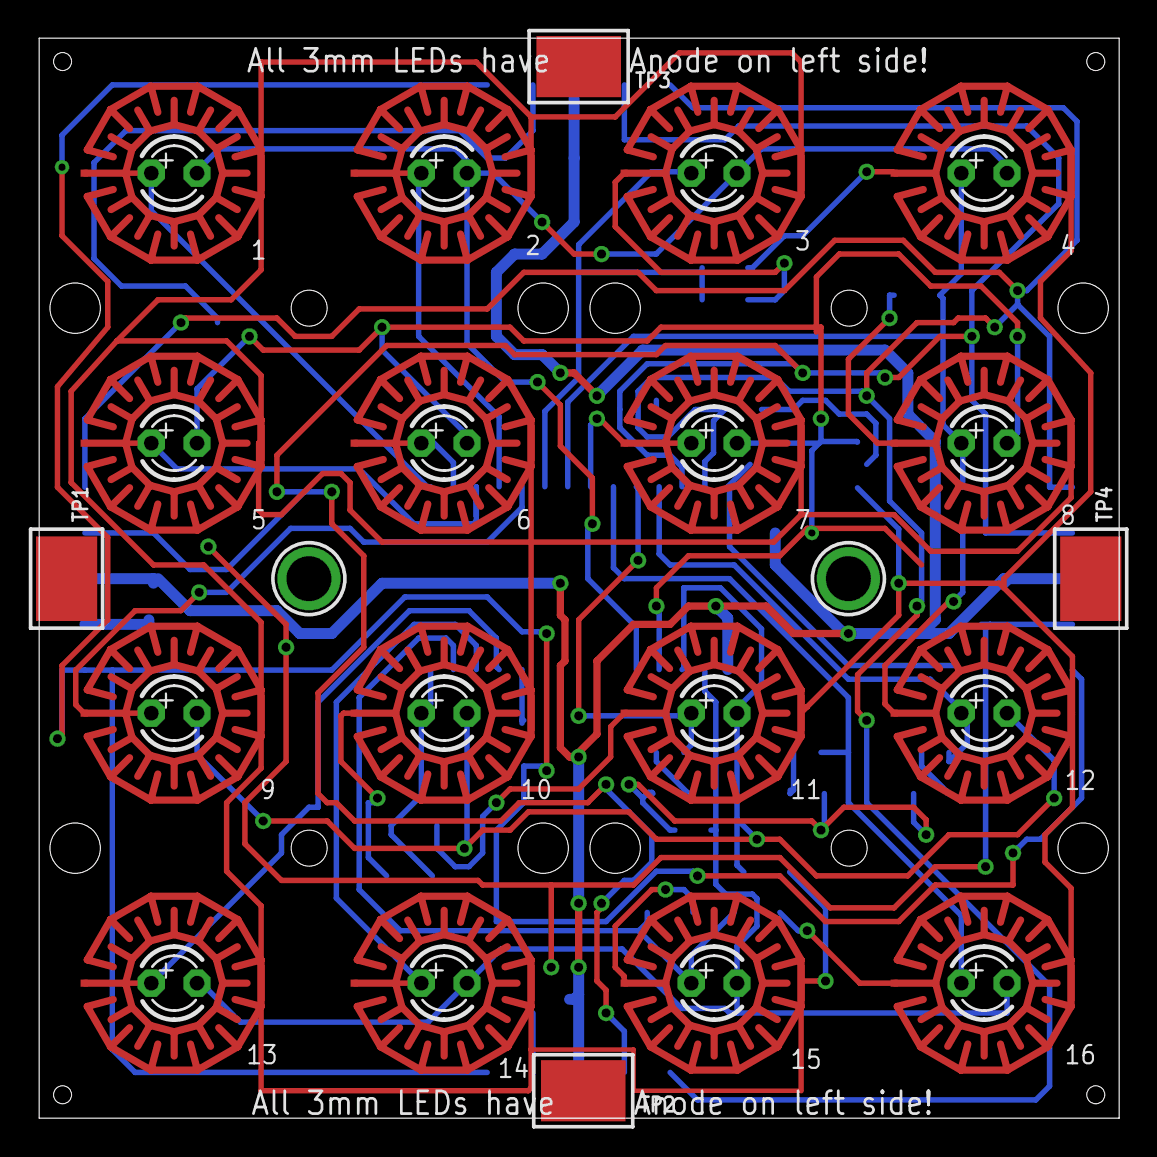
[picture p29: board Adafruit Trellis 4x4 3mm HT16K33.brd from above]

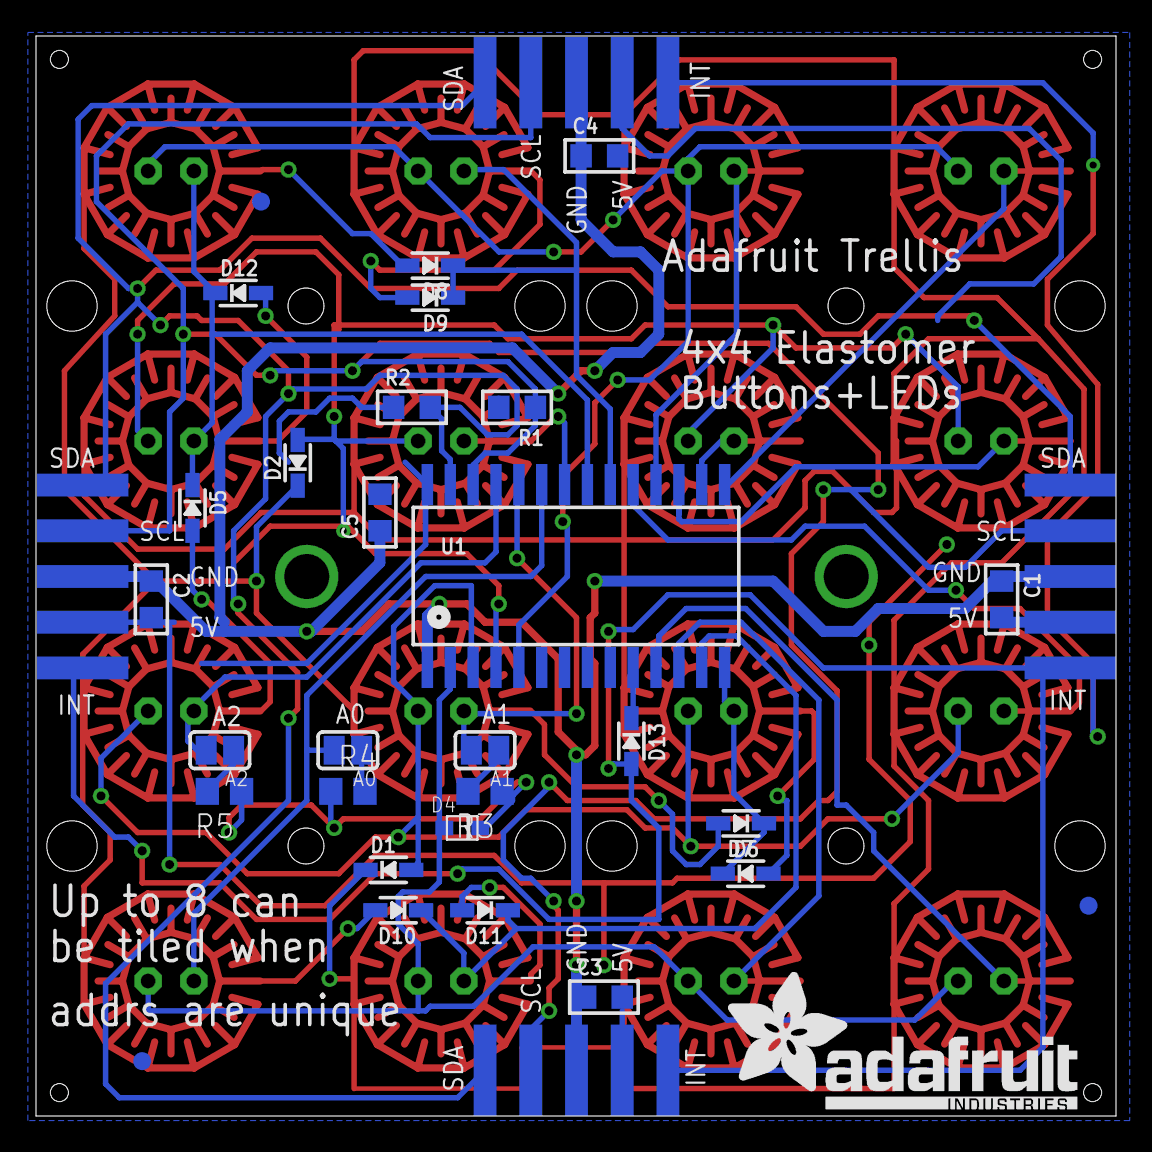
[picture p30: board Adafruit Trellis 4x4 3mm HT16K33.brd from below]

Board: 2 copper layers, 60.0 x 60.0 mm, 42 parts (34 on the bottom side), 39 nets.

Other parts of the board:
U$3: ADAFRUIT_TEXT_20MM

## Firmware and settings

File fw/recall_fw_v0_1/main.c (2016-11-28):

/****************************************************************************
;*	Microchip Technology Inc. 2007                                      *
;*	Assembler version:  XC8 v1.34                                       *
;*	Filename:                                                           *
;*		main.c (main routine)                                       *
;*	Dependents:                                                         *
;*                                                                          *
;*	April 13, 2015                                                      *
;*      PIC10(L)32X Developmental Board                                     *
;*      Demonstration program:                                              *
;*          After applying power to the PIC10(L)F32X Development Board,     *
;*          LED (D1) will automatically turn on.  Turn POT1 clockwise       *
;*          to increase the brightness of LED (D2).  Press switch (SW1)     *
;*          to turn both LEDs D1 and D2 off, release switch (SW1) and       *
;*          LEDs D1 and D2 will turn on.                                    *
;*                                                                          *
;****************************************************************************/


/*
Copyright (c) 2015 released Microchip Technology Inc.  All rights reserved.

Microchip licenses to you the right to use, modify, copy and distribute
Software only when embedded on a Microchip microcontroller or digital signal
controller that is integrated into your product or third party product
(pursuant to the sublicense terms in the accompanying license agreement).

You should refer to the license agreement accompanying this Software for
additional information regarding your rights and obligations.

SOFTWARE AND DOCUMENTATION ARE PROVIDED "AS IS" WITHOUT WARRANTY OF ANY KIND,
EITHER EXPRESS OR IMPLIED, INCLUDING WITHOUT LIMITATION, ANY WARRANTY OF
MERCHANTABILITY, TITLE, NON-INFRINGEMENT AND FITNESS FOR A PARTICULAR PURPOSE.
IN NO EVENT SHALL MICROCHIP OR ITS LICENSORS BE LIABLE OR OBLIGATED UNDER
CONTRACT, NEGLIGENCE, STRICT LIABILITY, CONTRIBUTION, BREACH OF WARRANTY, OR
OTHER LEGAL EQUITABLE THEORY ANY DIRECT OR INDIRECT DAMAGES OR EXPENSES
INCLUDING BUT NOT LIMITED TO ANY INCIDENTAL, SPECIAL, INDIRECT, PUNITIVE OR
CONSEQUENTIAL DAMAGES, LOST PROFITS OR LOST DATA, COST OF PROCUREMENT OF
SUBSTITUTE GOODS, TECHNOLOGY, SERVICES, OR ANY CLAIMS BY THIRD PARTIES
(INCLUDING BUT NOT LIMITED TO ANY DEFENSE THEREOF), OR OTHER SIMILAR COSTS.
*/


#include "device_initialize.h"

uint8_t led_state = 0;  ///0:off, 1:on/blinking

// Main application
void main(void)
{
    SYSTEM_Initialize();    // Initialize the device
    
    //Configure RA0 for button
    TRISAbits.TRISA0 = 1;   // Set Channel RA0 as input
    WPUAbits.WPUA0 = 1;     // Enable weak pull up
    ANSELAbits.ANSA0 = 0;   //Digital I/O
    OPTION_REGbits.nWPUEN = 0;  //Clear weak pull enable
    IOCANbits.IOCAN0 = 1;       //Enable interrupt on negative edge
    IOCAPbits.IOCAP0 = 0;       //Disable interrupt on positive edge
    INTCONbits.IOCIE = 1;       //Enable IOC interrupt
            
    //Configure RA2 for LED
    TRISAbits.TRISA2 = 0;   // Set Channel RA2 as output
    LATAbits.LATA2 = 0;     // Set RA2 (LED D1) high

    while (1)
    {
        //TEST CODE FOR BLINKING LED
//        if(IOCAFbits.IOCAF0==1 && led_state==0) {
//            IOCAFbits.IOCAF0 = 0; //clear IOC flag
//            led_state = 1;
//            TMR2_StartTimer();
//            LATAbits.LATA2 = 1;
//            //debouncing timer?
//        }
//        else if (IOCAFbits.IOCAF0==1 && led_state==1) {
//            IOCAFbits.IOCAF0 = 0; //clear IOC flag
//            led_state = 0;
//            TMR2_StopTimer();
//            LATAbits.LATA2 = 0;
//        }
//        
//        //blink LED
//        if(PIR1bits.TMR2IF == 1)
//        {
//            //toggle LED
//            if (LATAbits.LATA2 == 0)
//            {
//                LATAbits.LATA2 = 1;
//            }
//            else
//            {
//                LATAbits.LATA2 = 0;
//            }
//            
//            //reset timer2
//            TMR2 = 0x00;
//            PIR1bits.TMR2IF = 0;
//        }
        //TEST CODE FOR BLINKING LED
        
        
        
        //TEST CODE FOR BASIC ON/OFF
        if(IOCAFbits.IOCAF0==1 && led_state==0) {
            LATAbits.LATA2 = 1;
            
//            //delay for button debounce
//            TMR2_StartTimer();
//            if(PIR1bits.TMR2IF == 1)
//            {
                IOCAFbits.IOCAF0 = 0; //clear IOC flag
                led_state = 1;
//                TMR2 = 0x00;
//                PIR1bits.TMR2IF = 0;
//                TMR2_StopTimer();
//            }
        }
        else if (IOCAFbits.IOCAF0==1 && led_state==1) {
            LATAbits.LATA2 = 0;
            
//            //delay for button debounce
//            TMR2_StartTimer();
//            if(PIR1bits.TMR2IF == 1)
//            {
                IOCAFbits.IOCAF0 = 0; //clear IOC flag
                led_state = 0;
//                TMR2 = 0x00;
//                PIR1bits.TMR2IF = 0;
//                TMR2_StopTimer();
//            }
        }
        //TEST CODE FOR BASIC ON/OFF
    }
}
// End of File

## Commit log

2016-08-17 Initialize Altium project for discrete solution.
    [BMD-300-Eval.PrjPcb, BMD-300-Eval_Top.SchDoc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]
2016-09-06 Updated recall libs and added schematic/layout for recall_mcu_trellis
    [2032_battery.STEP, Adafruit Trellis 3mm.stl, Adafruit Trellis 3mm.stp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]
2016-09-06 Added 3D model for MP2016
    [MP2016.step, MP2016_unit.step, recall.PcbLib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]
2016-09-07 Reduced PCB to 1x1, generated fab outputs
    [recall.PcbLib, recall_discrete_v0_1.SchDoc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]
2016-09-07 Finished 2 layer version of recall_mcu_v0_1
    [4-1437565-1.stp, recall.PcbLib, recall.SchLib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]
2016-09-07 Cleaned up recall_mcu_2L and finished layout for recal_mcu_v0_2
    [recall.PcbLib, recall.SchLib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]
2016-09-07 Progress with recall_ble_mod_v0_1 schematic
    [recall.PcbLib, recall.SchLib, recall_ble_mod_v0_1.PcbDoc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]
2016-09-09 Finished layout for recall_ble_mod_v0_1
    [BG_Clip_female.step, BG_Clip_female.stl, BG_Clip_male.step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]
2016-09-09 Cleaned up ble_mod, discrete, beginnings of a panel
    [recall.PcbLib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]
2016-09-09 Added Nordic components to libs
    [recall.SchLib, recall_ble_v0_1.PrjPcb, recall_ble_v0_1.SchDoc]
2016-09-12 Finished recall_ble_v0_1 layout and panelized for PCB Way
    [400101.DRL, 400101.GBL, 400101.GBO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]
2016-09-16 Created BG test enclosure for recall clip
    [bg_clip_cover.stl, bg_clip_female.step, bg_clip_female.stl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]
2016-09-16 Exported step files for recall_mcu
    [recall_mcu_2L_v0_1.PcbDoc, recall_mcu_2L_v0_1.PrjPcb, recall_mcu_v0_2.PcbDoc]
2016-09-21 Moved PIC source code to fw directory
    [PIC10F32x_Source_Code.X.production.obj]
2016-09-26 Separate projects for development
    [PIC10F32x_Source_Code.X.production.obj]
2016-09-27 Added PIC test firmware for recall v1
    [PIC10F32x_Source_Code.X.production.obj, recall_fw_v0_1.production.obj]
2016-09-27 Added LED blink code. Need to fix debouncing.
    [recall_fw_v0_1.production.obj, recall_mcu_2L_v0_1.SchDoc]
2016-11-28 Added quotes for injection molding in china
    [1611-23-T683.xls, Button.x_t, SKY Quotation (Recall )161124-01.xls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]

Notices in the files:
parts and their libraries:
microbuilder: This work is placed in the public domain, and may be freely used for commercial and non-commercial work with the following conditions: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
